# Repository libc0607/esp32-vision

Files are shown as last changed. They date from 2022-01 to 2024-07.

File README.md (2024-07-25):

本项目已停止更新，已停止任何形式的技术支持。但您仍然可以查看全部开源资料，并在遵守开源协议的情况下使用。  
如果您遇到任何问题，可以学习那位的美德后自行解决，也可以在教令院找阿帽。阿帽不好听吗？  

---

# ESP32 神之眼 Genshin Impact Vision

Inazuma_Electro_Demo (https://www.youtube.com/watch?v=uiCPUxYVVak "Inazuma_Electro_Demo")  

[Bilibili BV1Fr4y1z7yS: 下北泽元素力测试](https://www.bilibili.com/video/BV1Fr4y1z7yS)  
[Bilibili BV1ir4y1r7ZS: 给刻师傅做个神之眼](https://www.bilibili.com/video/BV1ir4y1r7ZS)  
[Bilibili BV1hS4y1D7fo：蒙德外壳+圆版 测试](https://www.bilibili.com/video/BV1hS4y1D7fo)  
[Bilibili BV1a34y1s7b5：稻妻外壳+圆版 测试](https://www.bilibili.com/video/BV1a34y1s7b5)  
[Bilibili BV13S4y1e7Yu：蓝牙切换视频测试](https://www.bilibili.com/video/BV13S4y1e7Yu)  
[Bilibili BV13S4y1e7Yu：须弥外壳](https://www.bilibili.com/video/BV1ma41197kk)  

**警告：如果你没有能够完全理解整个设计的能力，那就不推荐做。** 因为我也不知道又会遇到什么坑  

**这里不是 B 站 up [渣渣一块钱4个](https://space.bilibili.com/14958846) 的代码仓库**，别做错了。详情见下方 [消歧义补丁](https://github.com/libc0607/esp32-vision#%E6%B6%88%E6%AD%A7%E4%B9%89%E8%A1%A5%E4%B8%81) 一节  

如果你是第一次尝试电子制作，或是不确定能否在缺乏教程的情况下自行完成以 0402 元件为主的中高密度 PCB 焊接及调试，那么推荐你从 [渣渣一块钱4个：电子版璃月神之眼制作教程](https://www.bilibili.com/video/BV1HS4y1b7tQ) 做起，他的教程十分详细，难度和成本都比较低，可以快速做出一个能用的成品。  

另外我也有一个基于小渣渣的设计缩水的版本，使用他修改的外壳，基于 GPL 3.0 开源，对量产成本做了优化；  
见 [libc0607/vision-c3-youth](https://github.com/libc0607/vision-c3-youth)   
但我没有在量产，在卖的都不是我，所以我不是客服，遇到问题你自己看看源码（  

## 我想自己做一个，且不怕翻车，该从哪开始？ 
但是真的很容易翻车，如果你真的想好了……。  
你可以先看 [渣渣一块钱4个：电子版璃月神之眼制作教程](https://www.bilibili.com/video/BV1HS4y1b7tQ)，大体流程是相同的  

 - 参考 [PCB 设计](https://github.com/libc0607/esp32-vision#pcb-%E8%AE%BE%E8%AE%A1) 一节中的链接，在 LCEDA 中[导出 Gerber](https://docs.lceda.cn/cn/PCB/Gerber-Generate/index.html)，送到嘉立创下单（[PCB 下单指引](https://www.jlc.com/portal/server_guide_35092.html)）  
 - 如果你对自己的焊接水平没有自信，需要 SMT，还需要[导出 BOM](https://docs.lceda.cn/cn/Schematic/Export-BOM/index.html) 以及[贴片坐标](https://docs.lceda.cn/cn/PCB/Export-Coordinate/index.html)，参照[嘉立创的下单教程](https://www.jlc.com/portal/server_guide_35102.html)进行 SMT 下单
 - 拿到 PCB 后完成全部元件焊接，确保硬件没有问题 
 - 在 [Arduino IDE](https://www.arduino.cc/en/software) 中装好 [arduino-esp32](https://github.com/espressif/arduino-esp32) 环境，并按照代码前的注释信息安装好其他依赖  
 - 按照代码前的注释信息，编译并上传程序至板载的 ESP32 中，测试基本功能是否正常；你应该使用带有 EN 和 IO0 接口的 ESP32 下载器   
 - 下载[外壳的 STL 文件](https://github.com/libc0607/esp32-vision/tree/main/stl)，通过 3D 打印制作外壳；你也许会想要在 [三维猴](https://www.sanweihou.com/) 或 [未来工厂](https://www.wenext.cn/) 下单  
 - 将打印好的外壳进行打磨及喷漆，可以参考 [渣渣一块钱4个：外壳喷漆教程](https://www.bilibili.com/video/BV1cY4y1a7CQ) 
 - 按照对应[外壳文件夹](https://github.com/libc0607/esp32-vision/tree/main/stl)下的 README 进行外壳及整机的组装  
 - 按照 [代码 README](https://github.com/libc0607/esp32-vision/tree/main/src/vision_sdcard_mjpeg) 下的指引，上传文件至内部存储中，并进行参数配置
 - Enjoy!
 
如果你想在 渣渣一块钱四个 的设计中，移植使用蓝牙 iTag 进行遥控的代码，这里有一个我整理出来的最小示例大概能帮到你：[ble_itag_demo](https://github.com/libc0607/esp32-vision/blob/main/src/ble_itag_demo/ble_itag_demo.ino)  
 
## 硬件特性
以下描述的是 V3.3 版本的特性：  
 - 1.54 寸 LCD（方版）或 1.28 寸 LCD （圆版）
 - ESP32-PICO-D4 核心，可以 Wi-Fi 上传
 - 内部显示的内容作为图片或者视频存在，可以在 SPIFFS 或 SD Nand 中存放图片/视频，理论上可以 128M ~ 8G  
 - 内置 LIS2DW12 加速度传感器，支持敲击识别，重力感应功能觉得有点鸡肋就删了  
 - 外壳预留 TEMT6000 环境光强度传感器位置，12-bit（大约） PWM 调光
 - 锂电池充电管理使用 CN3165，带有 NTC 保护，通过电阻配置来支持 4.2V/4.35V/4.4V
 - 圆版电池 R40350 3.85V/435mAh，方版电池 403035 3.7V/450mAh
 - 低功耗 DC-DC 降压 ETA3425，低电量时 100% 导通，即断电电压由锂电池保护板决定  
 - 用了一个 SY6280AAC 让屏和 SD Nand 支持断电 
 - 支持且仅支持无线充电，需要外接无线充电模块并将线圈贴在外壳上；配套使用 华为 GT2 Pro 的无线充电座即可充电，淘宝大概卖 29  
 - 本体带有一个物理按键，暂时用于切换显示模式
 - 支持将 iTag 蓝牙防丢器作为按钮控制视频切换
 
本设计的整体思路是尽量省电，虽然 V3.3 增加了电池容量（…），但受体积限制和屏幕拖累，续航还是尿崩  
你可以通过修改配置文件，在显示效果和续航间选择合适的平衡；详见 [vision_sdcard_mjpeg](https://github.com/libc0607/esp32-vision/tree/main/src/vision_sdcard_mjpeg)  

由于 2022 年 6 月的某个时候嘉立创将 ESP32-PICO-D4 踢出了经济型 SMT，考虑到少量自制的可制造性，未来本设计很可能会因此做出一些调整；但 V3.3 已经是一个相对稳定的版本，如果你等不及了可以做或是自己修改。  
根据目前（2022.7）的[信息](https://t.me/avocado_leaks/4980)来看，须弥也是圆的，我猜电路大概是还能用的（吧…？），所以应该不用再大改了  

## PCB 设计  
PCB 圆版：   
V3.3: [OSHWHub: libc0607/esp32_vision_v3-3_gc9a01_rel](https://oshwhub.com/libc0607/esp32_vision_v3-3_gc9a01_rel)  

  

PCB 方版：  
V3.3: [OSHWHub: libc0607/esp32_vision_v3-3_st7789_rel](https://oshwhub.com/libc0607/esp32_vision_v3-3_st7789_rel)  
注：1.54 寸 ST7789 屏幕有很多厂家生产外形和引脚定义兼容的型号，但有一部分型号屏幕的侧面及背面漏光。  
由于把漆喷到一点都不漏光这件事不是很有操作性，所以推荐选择不漏光的版本；你可能需要问问卖家  
注2：屏幕可能存在色差，不同的屏色差不同，这个emmm就没什么低成本且可操作性强的解决方法，推荐把播放的视频用 AE 自己调个色  



关于本设计在 2022 年 6 月之前的物料成本，仅供参考：以每批次做 5 套为例，约为 120 ~ 140 元/套。  
该价格：不含消耗品及工具等；不考虑良率；不含邮费；PCB 白嫖嘉立创；SMT 贴基础库；  
其中由于屏幕价格，方版整体会比圆版便宜；整体数值可能随元器件价格波动（不过大概只会高吧x   
懒人包：648做5个，做不出来再补一单328（？）  

2022 年 7 月更新：由于 JLC 把 ESP32-PICO-D4 移出了经济版 SMT 可贴列表，单次贴片的工程费由原本的 50 元提高到了 150+50 元。（我这邮寄的还没用完呢你就涨价草（  
除非你自己搞得定 ESP32-PICO-D4 的手工焊接，否则这会带来很高的成本提升。  

## 软件
目前做了两版测试代码，可以实现基本功能，但都不算正式 Release。有待填坑；  

[vision_SPIFFS_GIF_video](https://github.com/libc0607/esp32-vision/tree/main/src/vision_SPIFFS_GIF_video)： 不贴 SD Nand，仅使用 ESP32 内部的 SPIFFS 作为存储的版本  
[vision_sdcard_mjpeg](https://github.com/libc0607/esp32-vision/tree/main/src/vision_sdcard_mjpeg)： 使用 SD Nand 作为存储，支持 Wi-Fi 上传，支持 OTA，支持蓝牙的版本  

vision_SPIFFS_GIF_video 为早期版本的产物，没有维护，不能保证运行在新版硬件上。  
后续主要更新会集中在 vision_sdcard_mjpeg 上  

## 外壳 
由于本人非专业，只在大二上过一晚上的 SolidWorks 课，原始工程的 SLDPRT 已经变成屎山，本着要脸的原则没有放出。  
但这里提供了 STL 格式的文件，可以直接拿去下单 3D 打印，想修改的话也可以逆向一下，或是使用如 C4D 等可以修改的软件自行修改。  

另，现版本由于个人不算满意，可能会继续改动，持续到我删掉这句话为止；请自行考虑风险。  

[蒙德版外壳在这](https://github.com/libc0607/esp32-vision/tree/main/stl/mondstadt)   

[璃月版外壳在这](https://github.com/libc0607/esp32-vision/tree/main/stl/liyue)    

[稻妻的](https://github.com/libc0607/esp32-vision/tree/main/stl/inazuma)  

   

   

  

## 参考 & 引用
两个软件例子都参考了 [moononournation/RGB565_video](https://github.com/moononournation/RGB565_video)   
以及 DFRobot_LIS 的 tapInterrupt 示例、ESP32 Arduino 中的 SDWebServer 和 OTAWebUpdater 示例  
蓝牙 iTag 部分参考自 [100-x-arduino.blogspot.com](http://100-x-arduino.blogspot.com/)  
元素图标来自 [Bilibili: 鱼翅翅Kira](https://space.bilibili.com/2292091)   
外壳的处理方法是从 @云梦泽创意空间 的群文件中学到的   
野兽先辈忘了从哪搞来的了。。  
如果还有遗漏请指出谢谢茄子  

## 消歧义补丁
**这里不是 B 站 up [渣渣一块钱4个](https://space.bilibili.com/14958846) 的代码仓库**，别做错了。  

我的设计和他的设计是**两套独立的设计，代码不通用，硬件不通用，外壳不通用**，开源协议也不同，只是碰巧外观都是神之眼。。  
如果你只是想要一颗挂件，被神明注视一下下，我推荐优先考虑他的设计，因为他的教程详细丰富，群里活人多，翻车严重的话还能买个他的核心板用；  
我的这边只有 Github 这点儿文档，还总是不更新，代码还有 bug，做了会被神明注释掉的（  

### A. [渣渣一块钱4个](https://space.bilibili.com/14958846) 的设计资料汇总
我这里仅作为参考，不对内容做保证，不保证完整性，以原作者为准，请自行检查是否有最新版。  
别做错了，别做混了，别问我哪里和哪里能不能通用。。。  
圆版 PCB：[OSHWHub: 神之眼挂件V1.1](https://oshwhub.com/Myzhazha/esp32_pico-d4-video)  
方版 PCB：[OSHWHub: 璃月神之眼挂件](https://oshwhub.com/Myzhazha/li-yue-shen-zhi-yan-gua-jian)  
方版教程：[渣渣一块钱4个：电子版璃月神之眼制作教程](https://www.bilibili.com/video/BV1HS4y1b7tQ)  
方版效果：[渣渣一块钱4个：璃月电子版神之眼](https://www.bilibili.com/video/BV1DY4y1b7GN)  
圆版教程：[渣渣一块钱4个：电子版神之眼（蒙德）开源说明](https://www.bilibili.com/read/cv15460352)  
圆版安装：[渣渣一块钱4个：神之眼圆形核心板安装教程](https://www.bilibili.com/video/BV1KB4y1m7H2)   
圆版效果：[渣渣一块钱4个：稻妻和蒙德电子版神之眼](https://www.bilibili.com/video/BV1sF411g7tc)    
外壳下单：[渣渣一块钱4个：神之眼外壳3D打印平台打印教程](https://www.bilibili.com/read/cv16117622)  
外壳喷漆：[渣渣一块钱4个：外壳喷漆教程](https://www.bilibili.com/video/BV1cY4y1a7CQ)   
视频格式转换：[渣渣一块钱4个：使用FFmpeg转换mjpeg格式](https://www.bilibili.com/read/cv15713513)  

他的 QQ 群：636426429  
他后续会制作大尺寸（大约你家墙上86盒那么大）的神之眼，而我暂时没有计划，如果需要可以关注他。  

### B. [我](https://space.bilibili.com/6509521) 的设计资料汇总
……就 全都在这 没别的了（   

### 我的设计和他的设计的关系

 - 电路部分各做各的，不通用，不过也有相互参考   
 - 程序部分各做各的，不通用  
 - 他的蒙德外壳和璃月外壳基于我的修改，但不通用
 - 他卖核心板（不含外壳），我不对外卖，所以想买的去找他
 - 他的外壳为 CC BY-NC-SA 协议，其余部分为 GPL 协议；我的全部设计为 CC BY-NC-SA 协议  

## 许可
本设计采用 [CC BY-NC-SA 4.0](http://creativecommons.org/licenses/by-nc-sa/4.0) 许可。（OSHWHub 上只能选 3.0 ..）  
我不卖成品，也不以任何形式卖套件，没精力搞。。  
但作为开源项目，你当然可以在遵守开源协议的情况下自己做一个玩；NC 是为了防止潜在的mhy法务部警告（？）。  
如果你还是充满好奇，可以看看 [《原神同人周边大陆地区正式运行指引V1.2》](https://weibo.com/ttarticle/p/show?id=2309404707028085113324)（不保证这里链接是最新版，请自己确认）  

## 免责声明  
这东西仅为个人 DIY 项目，作者不保证所公开的内容绝对可用，也不可能解决所有出现的问题。  
本设计的全部设计资料都已开源，这里的内容足够从零开始制作一个完全可用的成品，没有那种祖传的隐藏细节。  
如果你对组装细节有不清楚的地方，可以联系我补全，但我只会直接补全到 Github 上，以便他人参考。  
你应该考虑到所有可能存在的风险，包括但不限于各种可能的人身伤害、金钱损失和 Emotional Damage。  
滥用本项目造成的一切负面效果与作者无关，最终解释权归作者所有。

说真的，不推荐做，又费钱又费时间又容易翻车，还容易因为自己太菜而受到精神打击（

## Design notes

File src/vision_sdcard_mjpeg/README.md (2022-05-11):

# vision_sdcard_mjpeg
这里是 ESP32 Vision 的测试代码之一。  
由于 SPIFFS 的容量只能够存十秒上下的 GIF，很多花活可能整不出来；这个 Demo 使用了板上容量可高达 8GB 的 SD Nand 来支持整活。   
注：由于加入蓝牙时这堆代码已经变成屎山了，目前的蓝牙部分还有各种各样的 Bug，emmmm……  

## 测试效果 
[Bilibili BV13S4y1e7Yu](https://www.bilibili.com/video/BV13S4y1e7Yu)  
这里用于演示的视频片段见 [hydro_unaligned](https://github.com/libc0607/esp32-vision/tree/main/src/vision_sdcard_mjpeg/hydro_unaligned) 目录下  

## 硬件
目前版本的代码可配合 硬件版本 V3.3 使用。  
蓝牙按钮使用一种叫做 iTag 的防丢器，它的协议相比模拟 HID 键盘的蓝牙按钮要简单很多，比如淘宝上的 [这个](https://item.taobao.com/item.htm?id=556798481873)  
关于如何将 iTag 作为 ESP32 的输入按钮使用，这里有一个最小化的例程： [ble_itag_demo](https://github.com/libc0607/esp32-vision/tree/main/src/ble_itag_demo)  

这个例子没有使用到板上那个 0402 封装的 NTC；其他的电路，包括外接的环境光传感器以及 NTC 电阻都需要焊接才能正常工作。  
这个例子通过修改代码的方式同时支持 方版（ST7789）和 圆版（GC9A01），修改方式见下文。  

## 功能
 - 冷启动后，屏幕变灰，尝试连接名为 Celestia，密码为 mimitomo （默认，可在源码中更改）的 Wi-Fi  
 - 如果超时未连接成功则进入正常工作周期；短按按键超过 250ms 可以跳过这个超时过程  
 - 如果连接成功，屏幕变蓝，同时开启一个 WebServer，通过浏览器 http 访问该设备，可以上传 mjpeg 视频到 SD 卡中，可以修改配置文件
 - 上传过程中屏幕会变成橘色，LED 闪烁，上传结束后变回蓝色
 - 短按按键退出上传模式
 - 播放视频时可以按下按键暂停，短按暂停则进入浅度睡眠并关闭屏幕和背光；按下超过一秒（默认）则保持当前帧，开最大背光，进入浅度睡眠；再次按下会恢复播放
 - 循环模式：可以选择循环播放（常亮），或是播放视频一次后进入深度睡眠
 - 深度睡眠时，通过双击唤醒或者定时器唤醒（按键由于不是 RTC IO，无法用于深睡唤醒）
 - 如果近期使用过双击唤醒或是按下过按键，则接下来的几次定时器唤醒会较快，反之亦然
 - 如果电量低，它就也不亮了 （？又废话）
 - 支持动态亮度调节
 - 支持通过配置文件选择播放的 mjpeg，支持在网页中预览 mjpeg 文件（…的第一帧）
 - 支持通过配置文件设置屏幕方向
 - 支持在网页中 OTA 升级固件
 - 播放掉帧，性能堪忧（
 - 任何时候长按超过三秒都会被断电或是上电
 - 蓝牙启用后，可以使用蓝牙连接 iTag 来控制在两段视频间平滑切换（可能仍存在 bug（

## 编译 & 上传 & 初始化设置 

1. 安装 Arduino  
2. 安装 [espressif/arduino-esp32](https://github.com/espressif/arduino-esp32)  （仅在 V1.0.6 下测试过；高版本和下面某个库的兼容不好）
3. 安装 [moononournation/Arduino_GFX](https://github.com/moononournation/Arduino_GFX)  
4. 安装 [bitbank2/JPEGDEC](https://github.com/bitbank2/JPEGDEC)  
5. 安装 [DFRobot/DFRobot_LIS](https://github.com/DFRobot/DFRobot_LIS)  
6. 安装 [stevemarple/IniFile](https://github.com/stevemarple/IniFile)  
7. 下载这坨源码，打开
8. 选择：ESP32 Dev Module, 240MHz CPU, 80MHz Flash, DIO, 4MB(32Mb), (1.9M/190k), PSRAM Disable  
9. 上传
10. 建立名为 Celestia， 密码为 mimitomo 的 2.4GHz Wi-Fi，该网络中需要提供 DHCP 服务；（就是用电脑或者手机开热点的意思；并且由于需要加载 js，这个热点需要能访问互联网）  
11. 给板子上电  
12. 当看到板子连入该 Wi-Fi 后，在 DHCP 地址池中找到该设备，记录下其 IP 地址
13. 使用浏览器 http 打开其 IP 地址，下文以 192.168.1.200 为例；如果你的网络中支持 MDNS 服务也可以打开 http://vision.local    
14. 使用 curl 或是其他什么你熟悉的东西上传 index.htm, edit.htm, ota.htm 三个网页文件：curl -X POST -F "file=@index.htm" http://192.168.1.200/edit
15. 将你需要播放的东西通过 ffmpeg 或是其他的什么方式转为 240x240，大约 24fps 的 mjpeg 格式文件 （参考 [RGB565_video](https://github.com/moononournation/RGB565_video) 中的示例）
16. 使用浏览器打开 http://192.168.1.200 或 http://vision.local ，选择 “文件”，并使用上方的按钮上传 mjpeg 文件到 SD Nand 根目录
17. 在左侧列表中找到 config.txt 并编辑，设置 video 为需要播放的文件名，以 / 开头，例如 video=/loop.mjpeg， Ctrl+S 保存；该文件的语法参考 [stevemarple/IniFile](https://github.com/stevemarple/IniFile)   
18. 短按按键，看到屏幕一绿即为配置完成
19. 你就又获得了一颗下北泽神之眼 
20. 如果想要再次更改其中内容，只需要将其断电（板上开关）等个十几秒后再接通让它冷启动，即可重复上述相关步骤。

## 自定义配置 

配置文件 /config.txt 中的可自定义内容：   

```
 [vision]
 video=/loop.mjpeg           # 要播放的文件名。需要以 / 开头，并且文件名不要超过 8 个字符（短文件名），不然会出bug
 lcd_rotation=0              # LCD 的方向。取值范围 0~3，对应 0°, 90°, 180°, 270°，根据实际情况修改
 loop_mode=false             # 循环开关
 abloop_en=false             # 使能两段视频切换
 ble_mac=00:12:34:56:78:9a   # 你的 iTag 的 MAC 地址。可以通过例如 nRF Connect 这样的应用查看
```
目前的设定中，有 3 种工作模式：  
(a). 循环播放两段视频，通过 iTag 或双击来控制两段视频的切换  
 该模式下需要剪出 4 段视频，两个循环片段 a_loop 及 b_loop，以及两个过渡片段 a_setup 和 b_setup；   
 - loop_mode = true
 - abloop_en = true
 - ble_mac = \<iTag MAC address\>
 - 上传 /a_setup.mjpeg, /a_loop.mjpeg, /b_setup.mjpeg, /b_loop.mjpeg  
  
 Light Sleep后蓝牙连接会断开，需要等几秒才会重新连接  
 LED 会指示当前正在播放的是 A 视频还是 B 视频；  
 
(b). 循环单个视频
  该模式需要一段视频
 - 上传视频 (例如 hydro.mjpeg)
 - loop_mode = true
 - abloop_en = false
 - video = hydro.mjpeg
 
 (c). 单次播放后进入睡眠，通过双击唤醒
  该模式需要一段视频
 - 上传视频 (例如 hydro.mjpeg)
 - loop_mode = false
 - video = hydro.mjpeg

如果你想恢复默认值，只需要删除 /config.txt 并重启即可，会生成一个新的默认配置的文件。  
按键功能仅在 (a) (b) 下生效   

代码中有几个可以配置的地方（其中一部分可能在日后（如果有，咕）的版本中移入配置文件）：  
```

// 系统配置
#define CONFIG_FILENAME "/config.txt"       // SD Nand 根目录中的配置文件的名称。该文件如果不存在会自动生成。 
#define DEEP_SLEEP_SHORT_S  6               // 在最近一次敲击唤醒之后的 DEEP_SLEEP_SHORT_CNT 次睡眠前，会设置定时器使用 DEEP_SLEEP_SHORT_S 作为唤醒延时；否则使用 DEEP_SLEEP_LONG_S
#define DEEP_SLEEP_SHORT_CNT  6             // 每次检测到敲击唤醒后重置计数器
#define DEEP_SLEEP_LONG_S   30              // DEEP_SLEEP_LONG_S 和 DEEP_SLEEP_SHORT_S 是定时器唤醒的时间，单位是秒
#define BAT_ADC_THRESH_LOW  1700            // 低电压保护。当每一轮工作开始时，如果 ADC 读取到的电压读数低于这个值，就不会播放 GIF，直接进入下一轮睡眠
                                            // 由于 ESP32 的 ADC 质量不咋样，并且电池的截止电压也各自不同，所以没有换算成电压。
                                            // 你可以根据自己板子的情况尝试调节这个值。  

// 屏幕配置
//Arduino_GC9A01  *gfx = new Arduino_GC9A01(bus, PIN_TFT_RST, 2, true);
Arduino_ST7789  *gfx = new Arduino_ST7789(bus, PIN_TFT_RST, 0, true, 240, 240, 0, 0, 0, 80);
                                            // 在这里选择你的屏幕种类
#define LCD_BACKLIGHT_MIN_8B  16            // 屏幕背光的最低亮度，范围为 8bit（即最大值为 255）。
                                            // 每次运行时，程序将从环境光传感器那里得到的光强度 Map 到 LCD_BACKLIGHT_MIN_8B ~ 255 区间内，作为背光 PWM 的占空比。
#define LCD_PWM_FIR_LEN 32                  // 让背光的动态调节不要那么突然

// 网络设置
const char* wifi_ssid = "Celestia";         // 冷启动时尝试连接的 Wi-Fi 名称和密码
const char* wifi_pwd = "mimitomo";
#define WIFI_CONNECT_TIMEOUT_S 20           // 冷启动时尝试连接 Wi-Fi 的时间上限，单位为秒。
                                            // 超过这个时间还没有连接成功则直接进入正常工作，也可以用按键跳过
const char* wifi_host = "vision";           // MDNS 主机名。这样设置得到的结果形如 vision.local                             

```
## 早期版本
由于早期使用的分区是默认的 1.2M/1.2M/1.5M，加入 BLE 后空间不够了。。所以 BLE 版本改了分区  
加入 BLE 前的最后一个版本为 [78b3749](https://github.com/libc0607/esp32-vision/commit/78b3749)  

## TO-DOs
本来想用 ESP-NOW（例如 [Picoclick](https://github.com/makermoekoe/Picoclick-C3)），但国内好像没有那种买来就能用的  
iTag 虽然使人逻辑混乱，但有商品卖，且足够便宜，先凑合用着  

## 参考 
[moononournation/RGB565_video](https://github.com/moononournation/RGB565_video)   
ESP32 Arduino 中的 SDWebServer 和 OTAWebUpdater 示例  
雷元素图标来自 [Bilibili: 鱼翅翅Kira](https://space.bilibili.com/2292091)  
BLE iTag 相关代码抄自 [100-x-arduino.blogspot.com](http://100-x-arduino.blogspot.com/2018/05/itag-i-arduino-ide-czy-esp32-otworzy.html)  

## 免责声明  
这段代码仅用作测试，由于滥用造成的一切不好的后果和作者无关。  
如果其中的图片素材涉及侵权，请联系我删除。  
这段代码仅调通了功能，结构十分混乱，如有引发不适与我无关。

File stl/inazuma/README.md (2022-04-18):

# ESP32 Vision 稻妻版外壳组装指引  
 当前外壳版本 V1.1，适配圆版 PCB V3.3  

由于都是圆的和蒙德版基本一致，这里就只写不同的部分  

## 材料清单
这里仅列出与蒙德版的不同  
| 名称 							| 数量	| 备注					|
| :---							| :---		| :---					|
| M1.2\*4 螺丝 | 4  | |
| R40350 锂电池  | 1 |  |

## 安装  
过程基本与蒙德版一致，这里就随便放几个图  

  

  

  



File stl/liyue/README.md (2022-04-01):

# ESP32 Vision 璃月版外壳组装指引

当前外壳版本 V2.2，适配 PCB 版本 V3.3 ST7789  
由于外壳更新可能会出现教程图片前后不兼容的情况，这里保留了最初版的教程没有改动，版本更新带来的变动会单独列在下面；但具体可能还是要自己发挥一下  

本安装指引的内容仅作为参考，不作为标准流程，可能会随时间推移而失效。请一定清醒一点带着脑子，搞明白自己做的是什么该怎么做，造成损失自负。  
作为一个 DIY 项目，它当然充满瑕疵，过程中还可能会出现各种问题，还请自行发挥。  
作者保留最终解释权。  

## 材料清单
注：这里的淘宝链接没有任何利益关系，只是为了方便说明。你可以随便买。
| 名称 							| 数量	| 备注					|
| :---							| :---		| :---					|
| liyue-main*.STL				| 1			| 本体 	|
| liyue-cap*.STL					| 1			| 盖子					|
| 焊接调试好的电路板及屏幕		| 1			|						|
| 403035(~450mAh) 或稍小尺寸的锂电池		| 1			| 403035是最大的，其余能不能塞得进去自己判断 |
| NTC 热敏电阻 10k B3380 		| 1			| 焊线的那种，粘在电池旁边测温度的 |
| M1.2\*3 圆头螺丝 国标 					| 6		| 可以多买一点备用，头部什么形状其实……没所谓？						|
| M1.2  螺母 					| 6		| 可以多买一点备用，要确定它和上面的能拧到一起就行						|
| M1.5\*4 平头铜铆钉 | 1 | 	用作按键。例如 [这个](https://detail.tmall.com/item.htm?id=15757285605) |
| O型密封圈，外径3mm内径1.4mm线径0.8mm	| 可选 |	例如 [这个](https://item.taobao.com/item.htm?id=614352089868)。套在上面的铆钉上。它仅起到改善手感的功能，可以不用，反正也不可能防水的，我写是因为买都买了。。|
| FPC 排线 4P 1.5mm间距 3cm长 	| 1 		| 不是那种常见白色的，一定要耐高温（茶色），比如 [这个](https://item.taobao.com/item.htm?id=639292801110)	|
| TEMT6000X01 环境光传感器		| 1			| 焊到上面的排线上					|
| 无线充电用的隔磁片			| 若干		| 虽然下面模块会送，但需要两层|
| Qi 协议的无线充电接收模块 	| 1			| 比如 [这个](https://item.taobao.com/item.htm?id=626465407103) ；买线圈大一点的版本 |
| 线圈							| 可选		| 接收模块送的线圈比较小，如果你使用下面提到的充电座则可以换一个稍大的线圈来提高效率；对于这些常见接收模块，选择电感量 10uH ~ 12uH，直径不超过 34mm 即可，比如芯科泰的 L93 和 L104 都实测可用 |
| Qi 协议的无线充电发射模块		| 可选		| 外壳是按照 华为 GT2 Pro 的充电座的外形画的，那个充电器淘宝大概不到30，买来直接吸上就能用；也可以在接收模块同一家买|
| 30mm 边长正方形的低弧的玻璃  	| 1			| 比如 [这个](https://item.taobao.com/item.htm?id=591580399917) ；建议多买一点，运输过程中可能撞出裂痕，需要挑选|
| 透明的胶水 					| 若干		| 需要能仅依靠外壳那一圈的面积粘得住那一大块玻璃，我用的是 维修佬 E8000 | 
| 8mm 直径， 1mm 厚的强磁铁		| 1			| 和 华为 GT2 Pro 充电器 一起使用时，用来吸附定位 |
| 自喷漆，金色（香槟金）		| 若干		| 外壳上色	|
| 自喷漆，光油					| 可选 		| 喷了有点脏，不喷金色容易掉，自己选		|
| 马克笔，金色					| 可选		| 用于补瑕疵；手残建议买，颜色需要和上面自喷漆一致	|
| 美纹纸胶带					| 若干		| 喷漆时用	|
| 砂纸 | 可选 | 用来打磨 3D 打印件上由于支撑带来的瑕疵，需要细一点的，我用的 2000 感觉粗了，建议 2000 5000 10000 各买一点 |
| 补土 | 可选 | 如果 3D 打印件上有坑就自己补一下，我买的田宫那个感觉还行 |
| 漆包线| 可选 | 那种耳机线材。比如我买的 [这个](https://item.taobao.com/item.htm?id=650753503748) |  
| 青稞纸 | 可选 | 如果是大电池，贴在电池上防止被电路板上的元件划伤|

### 外壳喷漆  
拿出 3D 打印的外壳。检查外观，如果有坑就用补土填一下（下面的图都没有使用，按实际情况来）；    
使用粗砂纸和细砂纸打磨表面至没有明显的支撑凸起；     
使用美纹纸胶带将不想被喷漆的位置覆盖好，然后使用自喷漆在表面薄薄地均匀地喷涂数次。    

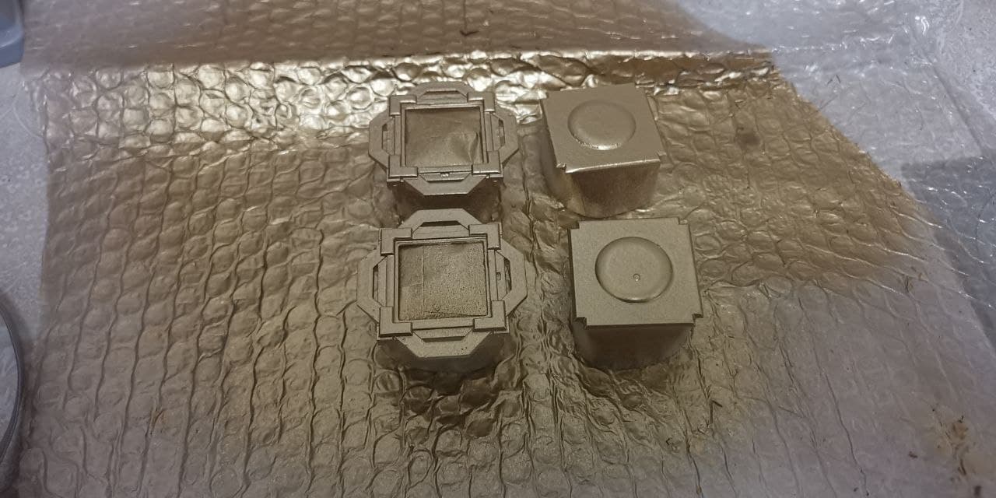
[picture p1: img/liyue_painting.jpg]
  

### 粘贴玻璃 
挑选一块没有裂痕没有瑕疵的 30 mm 边长低弧方形形玻璃。  
由于成本原因，它在运输过程中很容易出现刮花或者裂痕，所以建议多买一些到手后再挑；并且方的还有个更坑的问题，它四个角的圆角半径经常就tm不一样。。。还得挑   
同样地，装配过程中也要小心碰撞。方形玻璃建议按照实际用量的 4~5 倍购买，不然可能不太好挑。    

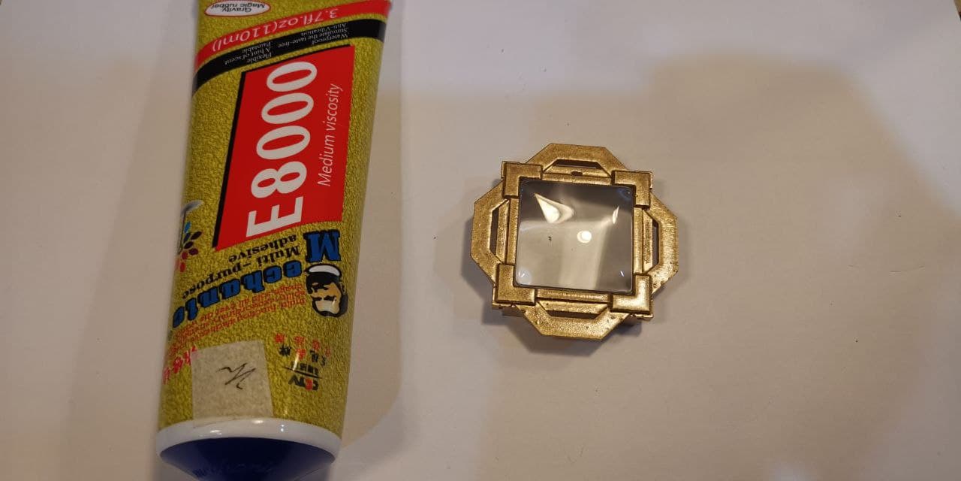
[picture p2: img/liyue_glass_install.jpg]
   

在外壳上均匀地挤一圈胶水，不要太多但是要能填满空隙，然后将玻璃放上去。注意要从多个侧面角度确认玻璃是否水平。  
由于 3D 打印精度和各地气温不同等原因，你可能需要在涂胶水前试一下玻璃能不能塞得进去。  
放上玻璃后胶水会溢出一些，我是将浸湿酒精的无尘布裹在镊子头部擦掉它们的，你也可以自由发挥。  
清理好溢出的胶水后，再次确认玻璃水平，使用美纹纸胶带将玻璃与外壳固定。我选择的这个胶水的固化大概需要一至两天，固化后暂时还没遇到过强度问题。  

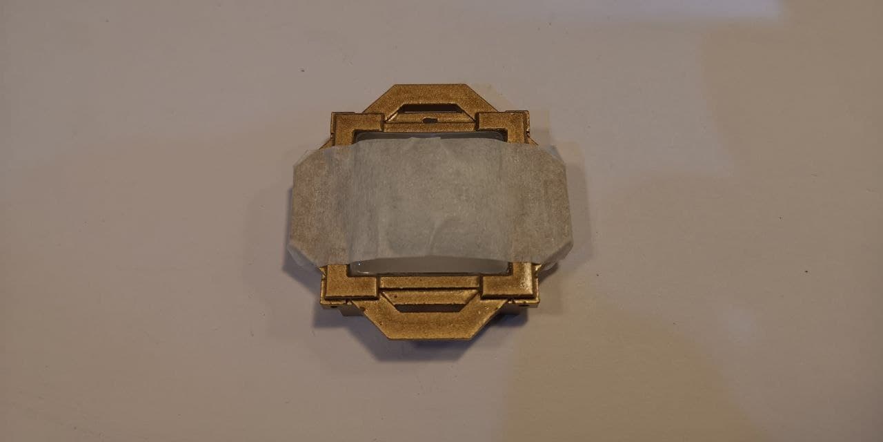
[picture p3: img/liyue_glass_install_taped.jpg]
  

### 安装环境光传感器  
准备一个 TEMT6000X01 环境光传感器，一条上表中提到的排线和胶水。  
将传感器如下图所示焊接在排线的引脚上。你可能需要像图上那样记录下引脚关系。  

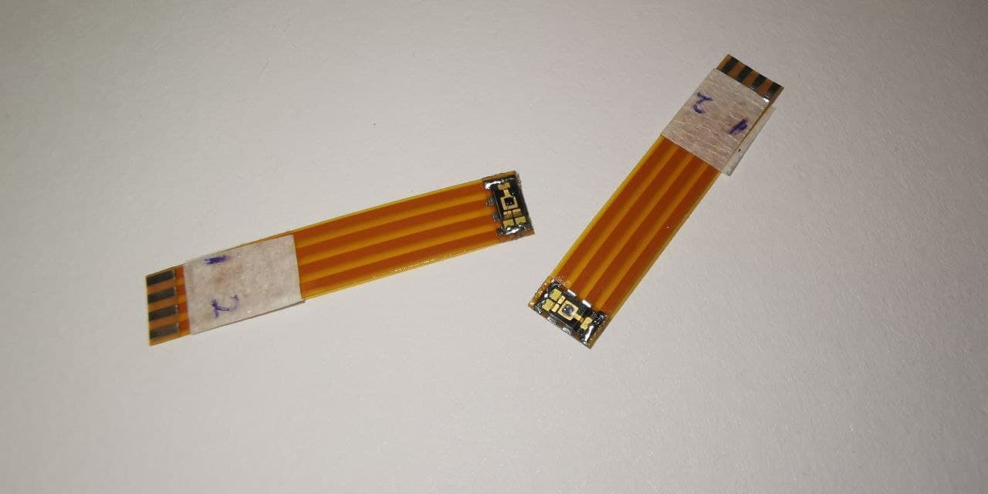
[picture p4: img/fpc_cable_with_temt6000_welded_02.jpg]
  

然后小心地将传感器所在位置折弯 90° 如下：  

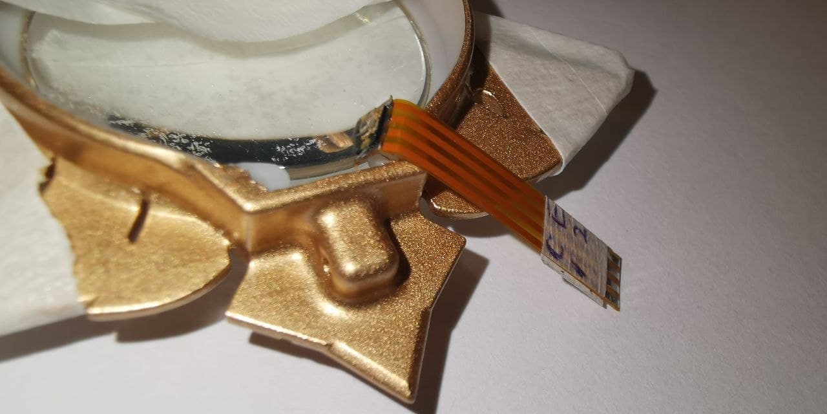
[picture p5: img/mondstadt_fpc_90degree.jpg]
  

在外壳的对应孔位挤一点胶水，并将传感器粘到孔中。  
使用美纹胶固定好玻璃和传感器，等待胶水固化，大约需要两天。  

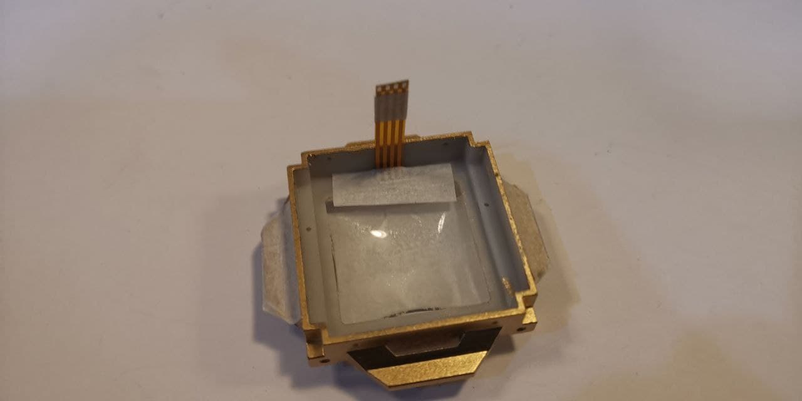
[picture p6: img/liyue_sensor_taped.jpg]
  

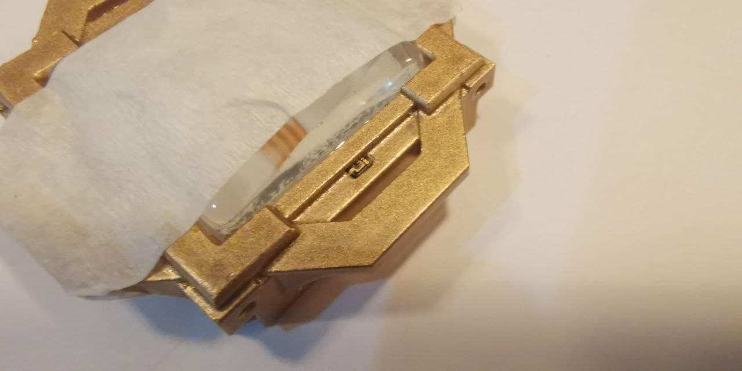
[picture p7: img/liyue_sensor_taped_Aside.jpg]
  

### 安装固定电路板用的螺母
在屏幕内侧有两个螺母位置，用来固定电路板。你需要把 2 颗 M1.2 螺母塞进去。内部情况如下图，平边与屏幕边缘平行。  

  

  

这里没有实物图，又是忘了拍了  

### 组装后壳 

后壳上需要嵌入剩下的 8 颗 M1.2 螺母。见下图，一共就八个坑  
将无线充电用的定位磁铁通过胶水粘贴在最大的坑里，注意和充电座放在一起试一下，别贴反了。。。  
确定极性后，用美纹胶带辅助定位，需要两天固化。

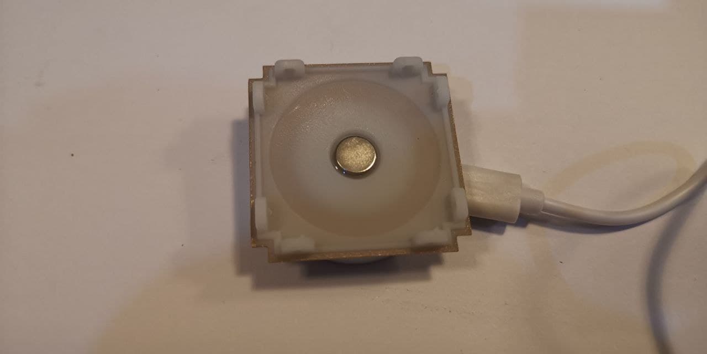
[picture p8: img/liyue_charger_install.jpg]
  

将无线充电的线圈粘贴上。  

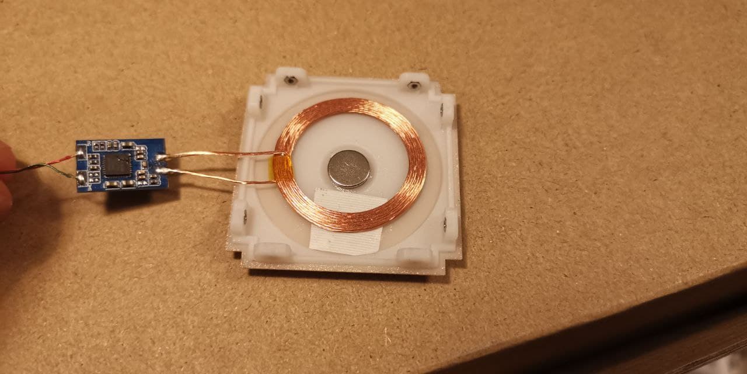
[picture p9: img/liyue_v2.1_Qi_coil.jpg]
    

按照后盖尺寸裁剪两片铁氧体隔磁片：  

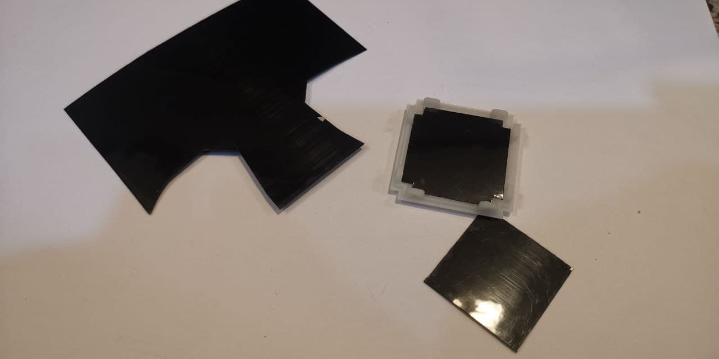
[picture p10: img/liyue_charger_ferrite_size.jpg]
  

将第一层隔磁片粘贴在线圈上，将无线充电模块粘贴在第一层隔磁片上；  

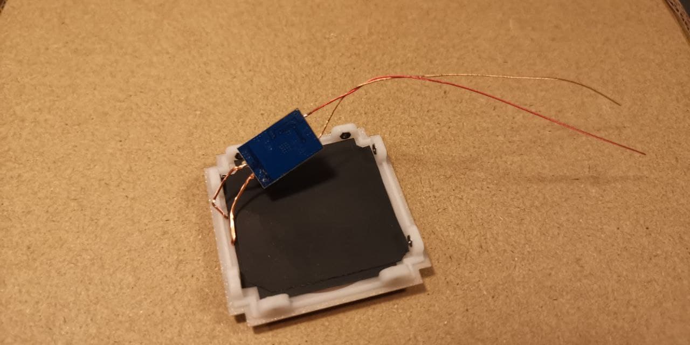
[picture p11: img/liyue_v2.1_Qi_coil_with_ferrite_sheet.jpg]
   

最后将第二层隔磁片粘贴在无线充电模块上，确保 PCB 上空有一层完整的隔磁片（下面几张图中并未安装，但实际需要）。  

### 安装电路  

你可以选择在安装电路板前先刷写固件。刷固件指引见 [/src](https://github.com/libc0607/esp32-vision/tree/main/src) 目录下，根据你的需要选择固件。  
由于这个 1.54 寸液晶屏背面不是金属，所以背面可以不贴绝缘胶带。  

按照引脚定义焊接好：环境光传感器的 2 条线；无线充电模块 2 条线；电池和 NTC 电阻共 3 条线（共用 GND）。    
如果发现原配的导线较硬，导致难以装配，可以将你不喜欢的线换成材料清单中提到的耳机线，将外皮剥掉使用线芯。  
完整的电路连接如下图。

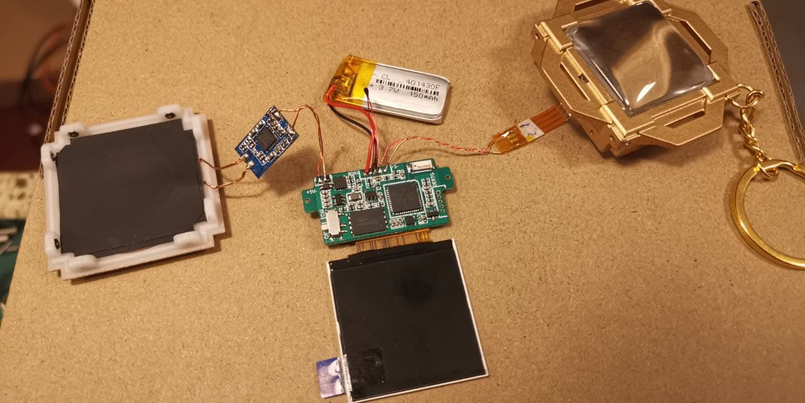
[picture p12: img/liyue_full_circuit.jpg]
   

将这些电路塞进去： 

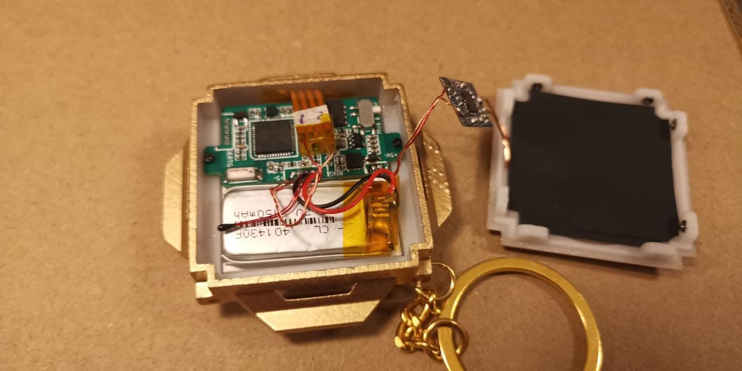
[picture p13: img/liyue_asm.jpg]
  

使用 2 颗 M1.2 螺丝将 PCB 固定在外壳上。盖上盖子，拧好周围的 8 颗螺丝，装配完成。 

--- 

### PCB V3.3 (STL V2.2) 改动  

#### 按键
PCB V3.3 (STL V2.2) 版本在侧面增加了一个按键，需要将按键塞进按键孔后再放入屏幕和电路板，像这样：  

  

  

尝试按动，能够按下能够回弹即可。在铆钉上套一个 O 型圈可以让它的手感更好一点，不过没有的话影响也不大。  

#### 电池安装
由于换用了403035 电池，安装结构需要做出调整：将无线充电模块贴在屏幕背面，然后将电池整个盖上去。  
你可能需要在电池上贴一层青稞纸来保护电池。  

#### 光传感器 
PCB V3.3 (STL V2.2) 版本为了正面美观，将光传感器移动到了侧面。  
按照同样的方式粘贴即可。

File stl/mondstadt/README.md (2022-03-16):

# ESP32 Vision 蒙德版外壳组装指引  
 
当前外壳版本 V2.3，适配圆版 PCB V3.3  
由于外壳更新可能会出现前后不兼容的情况，还是自己发挥一下  

本安装指引的内容仅作为参考，不作为标准流程，可能会随时间推移而失效。请一定清醒一点带着脑子，搞明白自己做的是什么该怎么做，造成损失自负。   
作为一个 DIY 项目，它当然充满瑕疵，过程中还可能会出现各种问题，还请自行发挥。  
作者保留最终解释权。  
（其实很多细节都和游戏中的模型有出入，暂时还没改的原因是因为 SolidWorks 水平太烂，SLDPRT 里变成屎山了，想改都没法改（（）  

## 材料清单
注：这里的淘宝链接没有任何利益关系，只是为了方便说明。你可以随便买。
| 名称 							| 数量	| 备注					|
| :---							| :---		| :---					|
| mondstadt-main*.STL			| 1			| 本体 	|
| mondstadt-cap*.STL				| 1			| 盖子					|
| 焊接调试好的电路板及屏幕		| 1			|						|
| 401120 或相近尺寸的锂电池		| 1			| 能不能塞得进去自己判断 |
| NTC 热敏电阻 10k B3380 		| 1			| 焊线的那种，粘在电池旁边测温度的 |
| M1.2\*4 圆头螺丝 					| 2/4			| 可以多买一点备用；大电池版仅用到 2 个						|
| M1.2\*6 圆头螺丝 					| 2			| 仅大电池版用到，可以多买一点备用						|
| M1.2 螺母 | 4 | 能和上面的螺丝拧到一起就行 |
| M1.5\*3 平头铜铆钉 | 1 | 用作按键。例如 [这个](https://detail.tmall.com/item.htm?id=15757285605) |
| O型密封圈，外径3mm内径1.4mm线径0.8mm| 可选 | 例如 [这个](https://item.taobao.com/item.htm?id=614352089868)。套在上面的铆钉上。它仅起到改善手感的功能，可以不用，反正也不可能防水的，我写是因为买都买了。。 |
| FPC 排线 4P 1.5mm间距 3cm长 	| 1 		| 不是那种常见白色的，一定要耐高温（茶色），比如 [这个](https://item.taobao.com/item.htm?id=639292801110)	|
| TEMT6000X01 环境光传感器		| 1			| 焊到上面的排线上					|
| 无线充电用的隔磁片			| 若干		| 虽然下面模块会送，但看情况可能需要两层|
| Qi 协议的无线充电接收模块 	| 1			| 比如 [这个](https://item.taobao.com/item.htm?id=626465407103) ；买线圈大一点的版本 |
| 线圈							| 可选		| 接收模块送的线圈比较小，如果你使用下面提到的充电座则可以换一个稍大的线圈来提高效率；对于这些常见接收模块，选择电感量 10uH ~ 12uH，直径不超过 34mm 即可，比如芯科泰的 L93 和 L104 都实测可用 |
| Qi 协议的无线充电发射模块		| 可选		| 外壳是按照 华为 GT2 Pro 的充电座的外形画的，那个充电器淘宝大概不到30，买来直接吸上就能用；也可以在接收模块同一家买|
| 35mm直径圆形的低弧的玻璃  	| 1			| 比如 [这个](https://item.taobao.com/item.htm?id=591580399917) ；建议多买一点，运输过程中可能撞出裂痕，需要挑选|
| 透明的胶水 					| 若干		| 需要能仅依靠外壳那一圈的面积粘得住那一大块玻璃，我用的是 维修佬 E8000 | 
| 8mm 直径， 1mm 厚的强磁铁		| 1			| 和 华为 GT2 Pro 充电器 一起使用时，用来吸附定位 |
| 自喷漆，金色（香槟金）		| 若干		| 外壳上色	|
| 自喷漆，光油					| 可选 		| 喷了有点脏，不喷金色容易掉，自己选		|
| 马克笔，金色					| 可选		| 用于补瑕疵；手残建议买，颜色需要和上面自喷漆一致	|
| 马克笔，黑色					| 1			| 用于给外壳上黑色的那几个位置涂色	| 
| 美纹纸胶带					| 若干		| 喷漆时用	|
| 砂纸 | 可选 | 用来打磨 3D 打印件上由于支撑带来的瑕疵，需要细一点的，我用的 2000 感觉粗了，建议 2000 5000 10000 各买一点 |
| 补土 | 可选 | 如果 3D 打印件上有坑就自己补一下，我买的田宫那个感觉还行 |
| 漆包线| 可选 | 那种耳机线材。比如我买的 [这个](https://item.taobao.com/item.htm?id=650753503748) |

### 外壳喷漆  
拿出 3D 打印的外壳。检查外观，如果有坑就用补土填一下（下面的图都没有使用，按实际情况来）；  
使用粗砂纸和细砂纸打磨表面至没有明显的支撑凸起；   
然后使用美纹纸胶带将不想被喷漆的位置覆盖好，然后使用自喷漆在表面薄薄地均匀地喷涂数次。  

如果上一步打磨过程中出现了奇怪的坑或者划痕，可以适当多喷一点点，但最忌心急喷一大堆。   

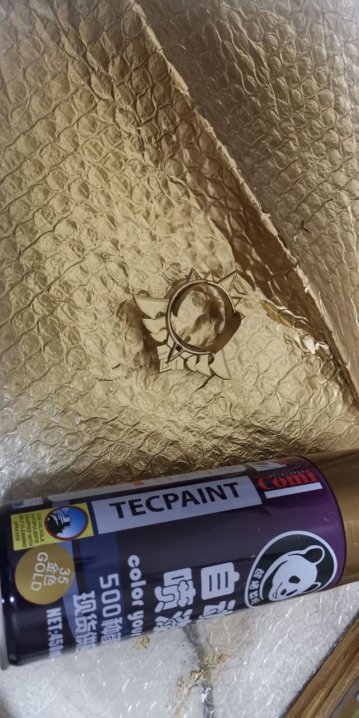
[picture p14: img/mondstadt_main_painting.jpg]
  
  

喷漆过程中请注意防护。等干透了再摸它。。  

喷光油的步骤可选，喷了的话外表显得有些脏，可能是我水平太烂（？）；不喷的话金色漆面可能容易掉。 

完成喷漆后，使用黑色马克笔把该涂成黑色的位置涂黑：  
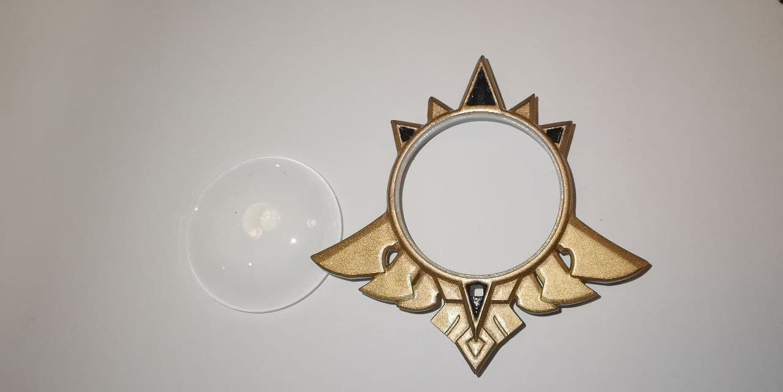
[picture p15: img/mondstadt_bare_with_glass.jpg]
  

### 粘贴玻璃 
挑选一块没有裂痕没有瑕疵的 35 mm 直径低弧圆形玻璃。  
由于成本原因，它在运输过程中很容易出现刮花或者裂痕，所以建议多买一些到手后再挑；同样地，装配过程中也要小心碰撞。我买过两批，总体良率大概在一半左右。    

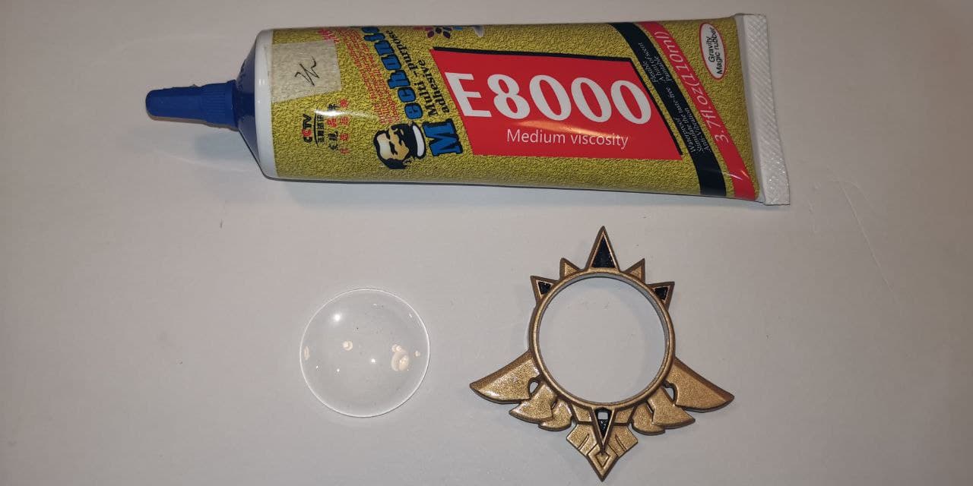
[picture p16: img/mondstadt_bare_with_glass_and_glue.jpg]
   

在外壳上均匀地挤一圈胶水，不要太多但是要能填满空隙，然后将玻璃放上去。注意要从多个侧面角度确认玻璃是否水平。  
由于 3D 打印精度和各地气温不同等原因，你可能需要在涂胶水前试一下玻璃能不能塞得进去。  
放上玻璃后胶水会溢出一些，我是将浸湿酒精的无尘布裹在镊子头部擦掉它们的，你也可以自由发挥。  

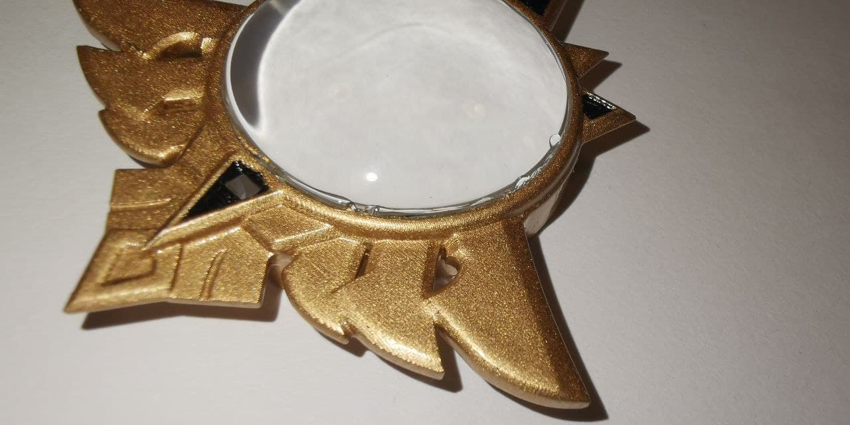
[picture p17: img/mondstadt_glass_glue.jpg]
  

清理好溢出的胶水后，再次确认玻璃水平，使用美纹纸胶带将玻璃与外壳固定。我选择的这个胶水的固化大概需要一至两天，固化后暂时还没遇到过强度问题。  

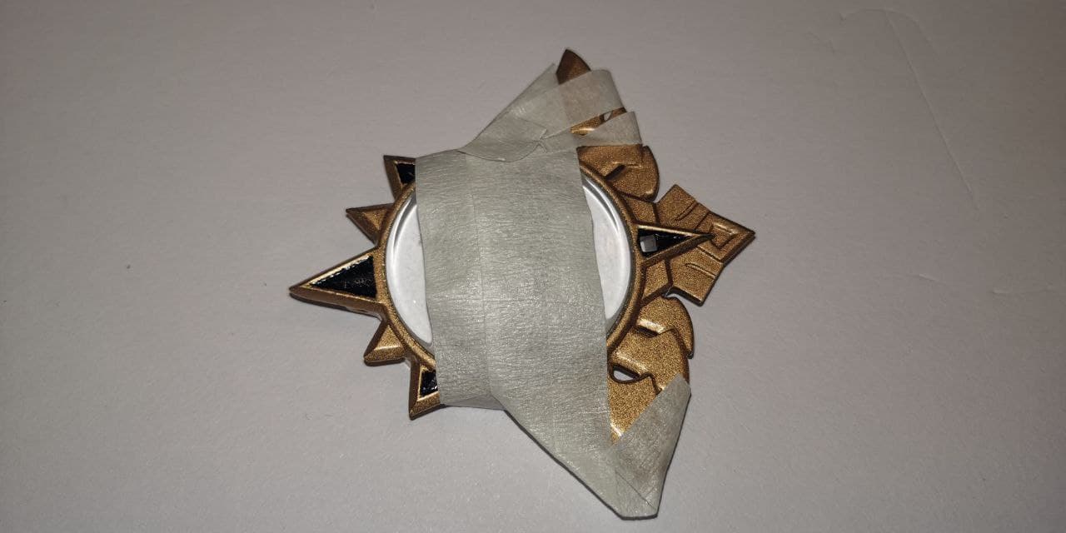
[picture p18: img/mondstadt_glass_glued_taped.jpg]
  

### 安装环境光传感器  
准备一个 TEMT6000X01 环境光传感器，一条上表中提到的排线和胶水。  
将传感器如下图所示焊接在排线的引脚上。你可能需要像图上那样记录下引脚关系。  

  

然后小心地将传感器所在位置折弯 90° 如下：  

  

在外壳的对应孔位挤一点胶水，并将传感器粘到孔中。  

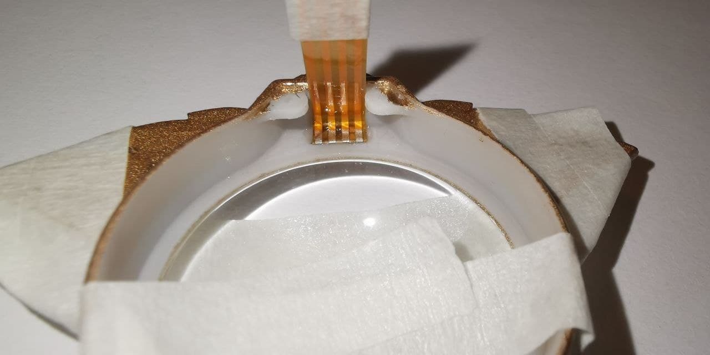
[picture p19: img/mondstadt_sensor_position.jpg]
  

使用美纹胶固定好传感器，等待胶水固化。  

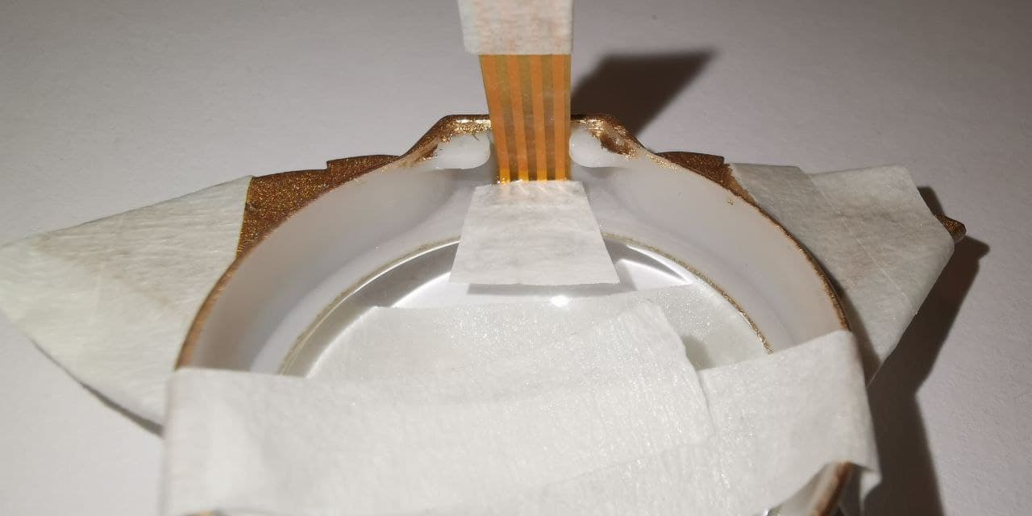
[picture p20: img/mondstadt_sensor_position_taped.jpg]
  

这时从外壳的正面应该可以正好露出传感器接收光线的部分。再在黑色部分均匀地覆盖一层胶水，同时作为固定和保护：  

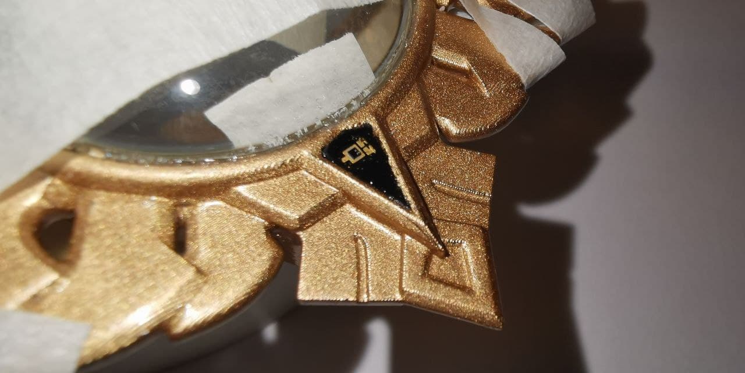
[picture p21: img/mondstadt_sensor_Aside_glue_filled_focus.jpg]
  

至此你已完成了外壳主体部分的组装。在等待两天胶水固化后即可拆除所有胶带。  

### 安装电路  
这一节的部分图片基于早期版本的电路和外壳，然后因为又懒又鸽导致还没更新，所以可能和实际的最新版本看上去不太一样。请动动脑  

你可以选择在安装电路板前先刷写固件。刷固件指引见 [/src](https://github.com/libc0607/esp32-vision/tree/main/src) 目录下，根据你的需要选择固件。  

将焊接好的电路板背面贴一层随便什么绝缘且最好导热好一点的东西，防止屏幕背板接触到电路板背面的触电造成短路：  
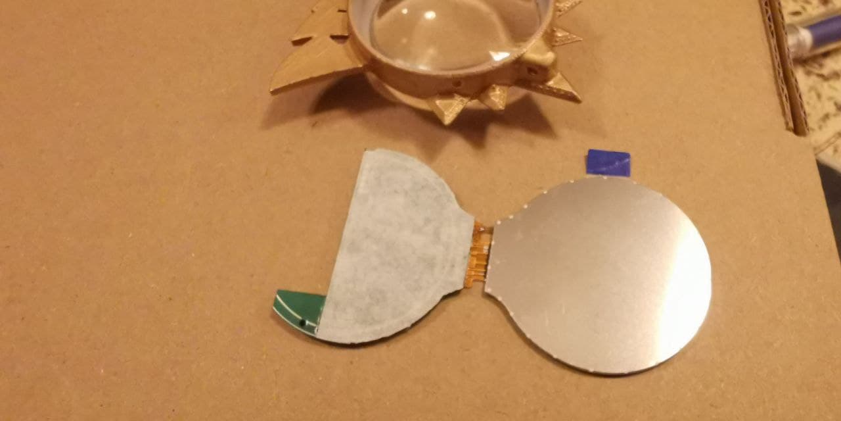
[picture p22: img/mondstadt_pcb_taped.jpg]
   
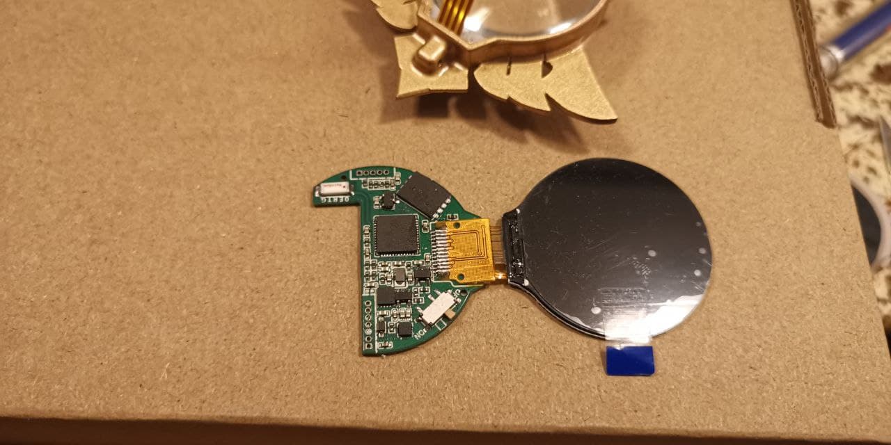
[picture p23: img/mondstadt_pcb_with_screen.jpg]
  

按照引脚定义焊接好：环境光传感器的 2 条线；无线充电模块 2 条线；电池和 NTC 电阻共 3 条线（共用 GND）。    
如果发现原配的导线较硬，导致难以装配，可以将你不喜欢的线换成材料清单中提到的耳机线，将外皮剥掉使用线芯。  

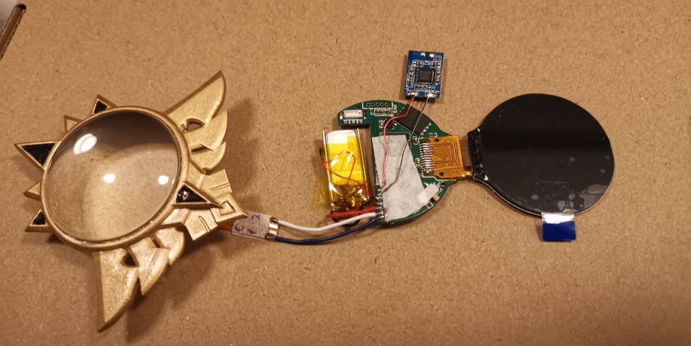
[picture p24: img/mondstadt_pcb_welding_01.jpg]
   

无线充电的线圈通过随便什么耐热的胶粘在后盖上，并在上面贴一层铁氧体隔磁片。钱多的同学也可以使用纳米晶隔磁片。  
然后在电路板的元件那面上再贴一小片隔磁片，将无线充电模块隔着这层隔磁片粘在电路板的上方附近。这一步没图，忘了拍了  

V3.3 版本在侧面增加了一个按键，需要将按键塞进按键孔后再放入屏幕和电路板，像这样：  

  

尝试按动，能够按下能够回弹即可。在铆钉上套一个 O 型圈可以让它的手感更好一点，不过没有的话影响也不大。  

最后就是像往肚子里塞肠子那样把它们都塞进去，只要能盖得上后盖，拧得上螺丝，就成功了（（  



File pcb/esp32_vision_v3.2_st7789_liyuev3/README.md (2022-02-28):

[OSHWHub: libc0607/esp32_vision_v3-2_liyuev3_st7789_rel](https://oshwhub.com/libc0607/esp32_vision_v3-2_liyuev3_st7789_rel)

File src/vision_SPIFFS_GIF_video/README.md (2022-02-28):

# vision_SPIFFS_GIF_video
这里是 ESP32 Vision 的测试代码之一。  
如果你只是想要一个可以简单地显示元素图标或者野兽仙贝，且不需要经常更改显示内容的钥匙链，那这个 Demo 适合你。   

## 测试效果 


见 [Bilibili BV1Fr4y1z7yS: 下北泽元素力测试 - bcccc23333](https://www.bilibili.com/video/BV1Fr4y1z7yS)  

## 硬件
目前版本的代码可配合 [方版（ST7789）](https://oshwhub.com/libc0607/esp32_vision_v3-2_liyuev3_st7789_rel) 及 [圆版（GC9A01）](https://oshwhub.com/libc0607/esp32_vision_v3-2_gc9a01_rel) 硬件版本 V3.2 使用。  

这个例子没有使用到板上的 SD Nand 和那个 0402 封装的 NTC，如果你想用这个例子那就可以不焊。（SD Nand 一片也十多块呢x）    
这个例子通过修改代码的方式同时支持 方版（ST7789）和 圆版（GC9A01），修改方式见下文。  

## 功能
 - 上电后从 SPIFFS 读取 GIF 图片
 - 播放完成后进入深度睡眠
 - 通过双击唤醒或是定时器唤醒（代码中默认 30s），再播放一次 GIF 图片，如此循环
 - 如果电量低，它就不亮了 （？废话）
 - 每次唤醒时根据环境光强度调节屏幕亮度  

## 编译 & 上传  

1. 安装 Arduino  
2. 安装 [espressif/arduino-esp32](https://github.com/espressif/arduino-esp32)  （仅在 V1.0.6 下测试过；高版本和下面某个库的兼容不好）
3. 安装 [moononournation/Arduino_GFX](https://github.com/moononournation/Arduino_GFX)  
4. 安装 [bitbank2/JPEGDEC](https://github.com/bitbank2/JPEGDEC)  
5. 安装 [DFRobot/DFRobot_LIS](https://github.com/DFRobot/DFRobot_LIS)  
6. 安装 [me-no-dev/arduino-esp32fs-plugin](https://github.com/me-no-dev/arduino-esp32fs-plugin)  
7. 下载这坨源码，打开
8. 选择：ESP32 Dev Module, 240MHz CPU, 80MHz Flash, DIO, 4MB(32Mb), No OTA (1M APP/3M SPIFFS), PSRAM Disable  
9. 上传
10. 将你需要的 GIF 文件通过 ffmpeg 或是其他的什么方式转为 240x240 @15fps，命名为 loop.gif ，放入 Data 文件夹中；这里也提供了两个示例 GIF 
11. "ESP32 Sketch Data upload" 写入 SPIFFS
12. 重启，你就获得了一颗下北泽神之眼 

## 自定义配置 
代码中有几个可以配置的地方： 
```
#define GIF_FILENAME "/loop.gif"      // SPIFFS 中的动图名，要以 / 开头

#define DEEP_SLEEP_TIME_S   30        // 深度睡眠后，定时器唤醒的时间，单位是秒

#define BAT_ADC_THRESH_LOW  1700      // 低电压保护。当每一轮工作开始时，如果 ADC 读取到的电压读数低于这个值，就不会播放 GIF，直接进入下一轮睡眠
                                      // 由于 ESP32 的 ADC 质量不咋样，所以没有换算成电压。你可以根据自己板子的情况尝试调节这个值。  

//Arduino_GC9A01  *gfx = new Arduino_GC9A01(bus, PIN_TFT_RST, 2, true);
Arduino_ST7789  *gfx = new Arduino_ST7789(bus, PIN_TFT_RST, 0, true, 240, 240, 0, 0);
                                      // 在这里选择你的屏幕种类

```
## 参考 
[moononournation/RGB565_video](https://github.com/moononournation/RGB565_video)  
雷元素图标来自 [Bilibili: 鱼翅翅Kira](https://space.bilibili.com/2292091)

## 免责声明  
这段代码仅用作测试，由于滥用造成的一切不好的后果和作者无关。  
如果其中的图片素材涉及侵权，请联系我删除。

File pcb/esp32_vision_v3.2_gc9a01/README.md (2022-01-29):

[OSHWHub: libc0607/esp32_vision_v3-2_gc9a01_rel](https://oshwhub.com/libc0607/esp32_vision_v3-2_gc9a01_rel)

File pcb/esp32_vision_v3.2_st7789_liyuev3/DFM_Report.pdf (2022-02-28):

高效的pcb制造分析软件

检查报告 | 关注公众号

时间2022-02-08

文件名：Gerber_PCB_esp32- | 层数：4 | 尺寸：38.00*18.00 mm


## 警示项


报告项目 | 类型 | 分析结果 | 描述与建议


最小间距 | 盘到线 | 0.11479 mm | 您的“焊盘到线”最小间距为4.52mil，会影响生产效率、品质良率，可能会导 致费用上涨，建议“焊盘到线”最小间距≥6mil


最小间距 | 线到线 | 0.11479 mm | 您的“最小线距”为4.82mil，会影响生产效率、品质良率，可能会导致费用上 涨，建议“密集区域”线距≥4mil、“普通区域”线距≥6mil


最小线宽 | 最小线宽 | 0.12 mm | 您的“最小线宽”为4.72mil，会影响生产效率、品质良率，可能会导致费用上 涨，建议“密集区域”线宽≥3.5mil、“普通区域”线宽≥6mil


孔大小 | 厚径比 | 0.2 mm | 您的“最小厚径比”为8.00，会影响生产效率、品质良率，可能会导致费用上 涨，建议“最小厚径比”<8:1


孔大小 | 最小孔径 | 0.2 mm | 您的“最小孔径”为0.20mm，会影响生产效率、品质良率，可能会导致费用上 涨，建议“最小孔径”≥0.3mm


孔环 | 过孔孔环 | 有 | 您的“过孔孔环”最小为infmil会影响产品可靠性，建议“过孔孔环”最小环 ≥ 5 mil


孔到线 | 插件孔到内层 | 0.23987 mm | 您的内层“插件孔到线”最小间距为11.06mil，会影响生产效率、品质良率，可 能会导致费用上涨，建议内层“插件孔到线”最小间距≥12mil


孔到线 | 插件孔到表层 | 0.23987 mm | 您的外层“插件孔到线”最小间距为11.06mil，会影响生产效率、品质良率，可 能会导致费用上涨，建议外层“插件到线”最小间距≥12mil


孔到线 | 过孔到表层 | 0.23987 mm | 您的外层“过孔到线”最小间距为9.44mil，会影响生产效率、品质良率，可能 会导致费用上涨，建议内层“过孔到线”最小间距≥10mil


孔上焊盘 | 过孔上焊盘 | 有 | 您的“设计”存在“孔在SMD焊盘上”，会影响焊盘的平整度，可能会导致焊 锡不良。

# 全部检查项

报告项目 | 类型 | 分析结果

电气信号 开短路 | 断头线 | 正常
| 孤立铜 | 正常
| 无效过孔 | 正常
| 片式SMD没连线路 | 正常
| 锐角 | 正常
最小线宽 | 最小线宽 | 6pis 0.12 mm
最小间距 | 线到线 | 62pis 0.11479 mm
| 盘到线 | 138pis 0.11479 mm
| 盘到盘 | 正常 0.11479 mm
最小焊盘 | BGA焊盘 | 正常
| 常规焊盘 | 正常
| 长条焊盘 | 正常 >0.25 mm
SMD间距 | 同网络SMD焊盘间距 | 正常 0.21987 mm
| 不同网络SMD焊盘间 距 | 正常 0.21987 mm
| 同器件焊盘间距 | 正常
| 不同器件焊盘间距 | 正常
网格铺铜 | 网格线宽 | 正常
| 网格线距 | 正常
孔大小 | 最小孔径 | 4pis 0.2 mm
| 最大孔径 | 正常
| 厚径比 | 1pis 0.2 mm
槽孔 | 最小槽宽 | 正常
| 最大槽宽 | 正常
| 槽长宽比 | 正常

孔环 | 过孔孔环 | 256pis 有
| 插件孔孔环 | 正常
孔到孔 | 同网络过孔 | 正常 0.25 mm
| 不同网络过孔 | 正常
| 插件孔 | 正常
孔到线 | 过孔到表层 | 94pis 0.23987 mm
| 插件孔到表层 | 5pis 0.23987 mm
| 过孔到内层 | 正常 0.23987 mm
| 插件孔到内层 | 2pis 0.23987 mm
| NPTH到铜 | 正常
板边距离 | 铜/PAD/线到板边距 离 | 正常
| SMD到板边距离 | 正常
| 孔到板边 | 正常
特殊孔 | 半孔 | 正常
| 盲埋孔 | 正常
| 盲埋孔距离 | 正常
| 激光孔 | 正常
| 正/长方形孔 | 正常
焊盘规格 | 焊盘大小异常 | 正常
| 封装内间距异常 | 正常
孔上焊盘 | 盘中孔 | 正常
| 插件孔 | 正常
| 过孔上焊盘 | 1pis 有
| 非金属孔 | 正常

阻焊开窗 | 阻焊异常 | 正常
| 阻焊盖线 | 正常
| 阻焊间隙 | 正常
| 同网络阻焊间隙 | 正常
| 漏阻焊桥 | 正常
| 同网络漏阻焊桥 | 正常
孔密度 | 孔密度 | 179个；26.17万/m²
沉金面积 | 沉金面积 | 30.55%
飞针点数 | 飞针点数 | 213
Mark点 | Mark点 | 正常
锣长分析 | 锣长分析 | 168.628m/㎡

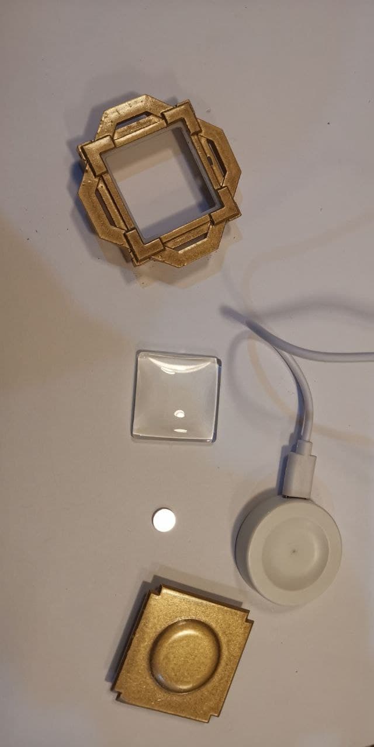
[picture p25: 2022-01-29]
img/liyue_glass_charger.jpg

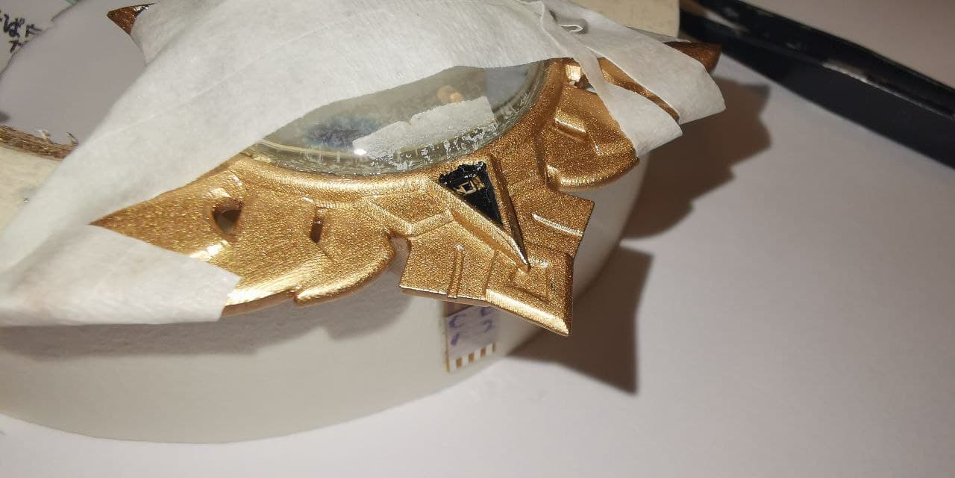
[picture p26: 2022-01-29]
img/mondstadt_sensor_Aside_glue_filled.jpg

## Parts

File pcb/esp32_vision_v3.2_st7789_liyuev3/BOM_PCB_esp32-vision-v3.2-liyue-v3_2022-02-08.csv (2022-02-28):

ID | Name | Designator | Footprint | Quantity | Manufacturer Part | Manufacturer | Supplier | Supplier Part | Price
1 | 1uF | C6 | C0402 | 1 | CL05A105KA5NQNC | SAMSUNG | LCSC | C52923 | 0.0211
2 | 3.3kΩ | R19 | R0402 | 1 | 0402WGF3301TCE | UniOhm | LCSC | C25890 | 0.0038
3 | 10uF | C1,C2,C4,C5,C8,C9,C10,C11,C13,C14,C15,C16,C17 | C0402 | 13 | CL05A106MQ5NUNC | SAMSUNG | LCSC | C15525 | 0.0312
4 | 4.7uF | C7 | C0402 | 1 | CL05A475MP5NRNC | SAMSUNG | LCSC | C23733 | 0.0361
5 | 100nF | C20 | C0402 | 1 | CL05B104KB54PNC | Samsung Electro-Mechanics | LCSC | C307331 | 0.039
6 | 100nF | C3,C12,C21 | C0402_NEW | 3 | CL05B104KO5NNNC | SAMSUNG | LCSC | C1525 | 0.0068
7 | A1251WV-5P | CN1,CN2 | CONN-TH_5P-P1.25_A1251WV-5P | 2 | A1251WV-5P | Changjiang Connectors | LCSC | C225093 | 0.6765
8 | 1N5819WS | D1 | SOD-323_L1.8-W1.3-LS2.5-RD | 1 | 1N5819WS | Guangdong Hottech | LCSC | C191023 | 0.1986
9 | AN2051-245 | L1 | ANT2051 | 1 | AN2051-245 | Rainsun | LCSC | C99727 | 49.05
10 | 2.2uH | L3 | L0806 | 1 | DFE201612E-2R2M=P2 | Murata Electronics | LCSC | C337893 | 1.0569
11 | AO3400A | Q2 | SOT-23-3_L2.9-W1.6-P1.90-LS2.8-BR | 1 | AO3400A | AOS | LCSC | C20917 | 0.9865
12 | 100K | R1 | R0402 | 1 | 0402WGF1003TCE | UniOhm | LCSC | C25741 | 0.0044
13 | 3.9K | R2,R6 | R0402 | 2 | 0402WGF3901TCE | UniOhm | LCSC | C51721 | 0.0047
14 | 10K | R3,R5 | R0402 | 2 | 0402WGF1002TCE | UniOhm | LCSC | C25744 | 0.0035
15 | 10 | R4 | R0402 | 1 | 0402WGF100JTCE | UniOhm | LCSC | C25077 | 0.0038
16 | 20K | R7,R17 | R0402 | 2 | 0402WGF2002TCE | UniOhm | LCSC | C25765 | 0.0039
17 | 10kΩ | R8 | R0402 | 1 | NTCG104BH103JT1 | TDK | LCSC | C92039 | 0.3362
18 | 15K | R9 | R0402 | 1 | 0402WGF1502TCE | UniOhm | LCSC | C25756 | 0.004
19 | 1M | R10,R11,R14,R18 | R0402 | 4 | 0402WGF1004TCE | UniOhm | LCSC | C26083 | 0.0042
20 | 2M | R13 | R0402 | 1 | 0402WGF2004TCE | UniOhm | LCSC | C11512 | 0.0057
21 | 100 | R15,R16 | R0402 | 2 | 0402WGF1000TCE | UniOhm | LCSC | C25076 | 0.0037
22 | MSK12C02 | SW1 | SW-TH_MSK12C02 | 1 | MSK12C02 | SHOU HAN | LCSC | C431540 | 0.3189
23 | ESP32-PICO-D4 | U1 | QFN-48_L7.0-W7.0-P0.50-BL-EP5.4 | 1 | ESP32-PICO-D4 | Espressif Systems | LCSC | C193707 | 22.9
24 | SY6280AAC | U3 | SOT-23-5_L3.0-W1.7-P0.95-LS2.8-BR | 1 | SY6280AAC | Silergy | LCSC | C55136 | 1.7091
25 | ETA3425S2F | U4 | SOT-23-5_L2.9-W1.6-P0.95-LS2.8-BL | 1 | ETA3425S2F | null | LCSC | C2890147
26 | CSNP1GCR01-BOW | U5 | LGA-8_L6.0-W8.0-P1.27-TL | 1 | CSNP1GCR01-BOW | CS(创世) | LCSC | C2691593 | 15.78
27 | CN3165 | U7 | DFN-8_L3.0-W3.0-P0.50-TL-EP | 1 | CN3165 | ShangHai Consonance Elec | LCSC | C559035 | 2.63
28 | LIS2DH12TR | U8 | LGA-12_L2.0-W2.0-P0.50-BL | 1 | LIS2DH12TR | STMicroelectronics | LCSC | C110926 | 6.47
29 | 1.25T-2A_C722633 | CN3 | CONN-TH_1.25T-2A_1.25T-2A | 1 | 1.25T-2A | CAX(创都) | LCSC | C722633 | 0.0407
30 | ST7789-1.54寸 | U2 | ST7789-1.54寸 | 1

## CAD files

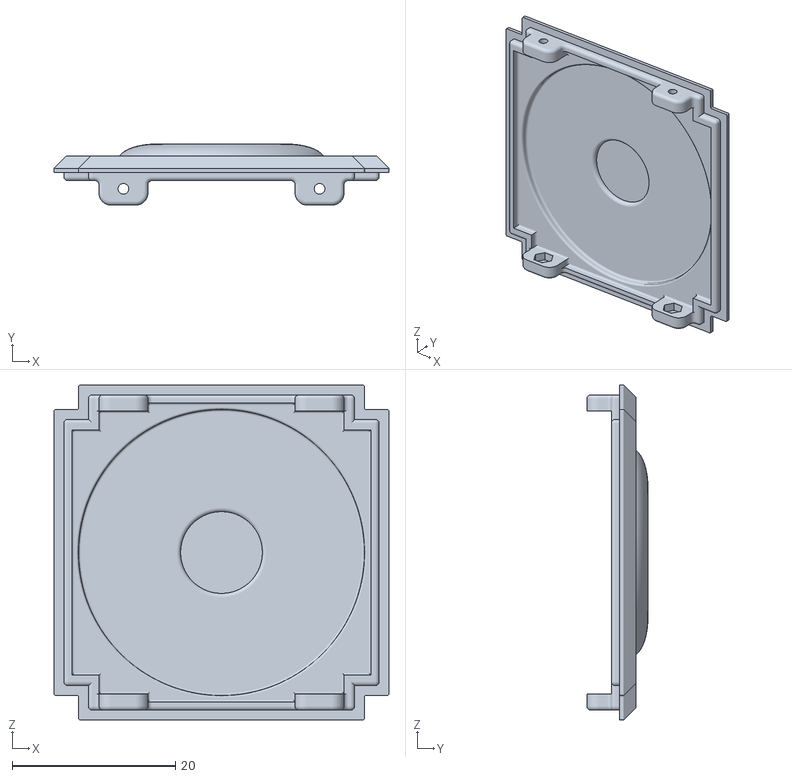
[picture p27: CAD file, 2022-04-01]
stl/liyue/liyue-v2.2-cap.STL
41.0 x 7.50 x 41.0

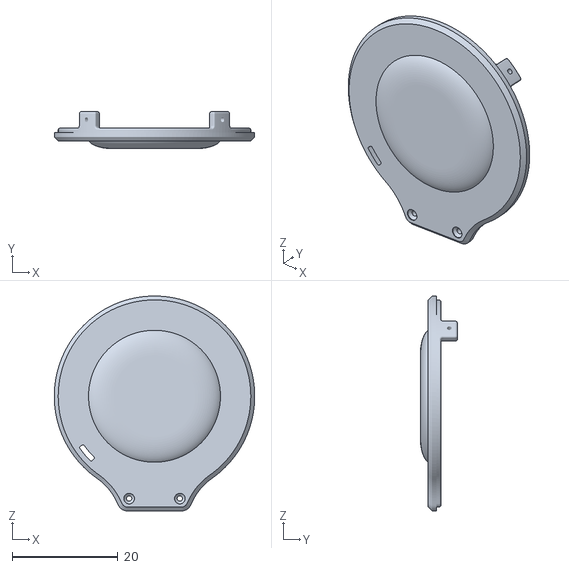
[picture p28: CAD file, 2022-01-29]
stl/mondstadt/mondstadt-cap-v2.1.STL
38.0 x 7.10 x 40.7

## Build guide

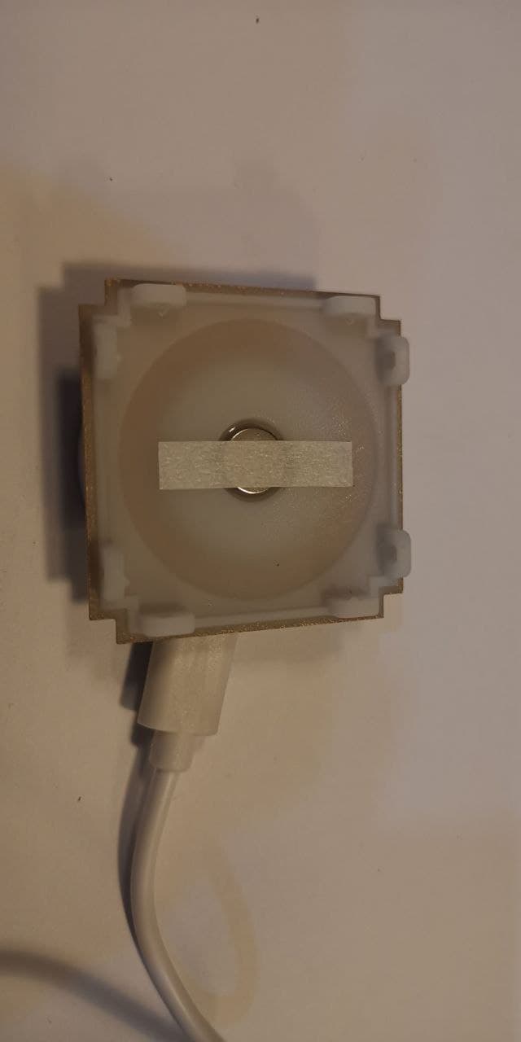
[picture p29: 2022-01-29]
img/liyue_charger_install_taped.jpg

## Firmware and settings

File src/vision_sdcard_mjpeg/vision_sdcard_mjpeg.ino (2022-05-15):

/*
   Vision V3.3 SD MJPEG WebServer OTA BLE DEMO
   Github: libc0607/esp32-vision

   ref:
   https://github.com/moononournation/RGB565_video 
   examples/SDWebServer
   examples/OTAWebUpdater

   WebServer bring-up:
   curl -X POST -F "file=@ota.htm" http://vision.local/edit
   curl -X POST -F "file=@index.htm" http://vision.local/edit
   curl -X POST -F "file=@edit.htm" http://vision.local/edit

   How-to in Arduino IDE:
    Choose:
      ESP32 Dev Module, 240MHz CPU, 80MHz Flash, DIO, 4MB(32Mb),
      Minimal SPIFFS (1.9MB with OTA/190kB SPIFFS), PSRAM Disable;
    upload;

   Dependencies:
     Install espressif/arduino-esp32 (V1.0.6, due to compatibility issue) first
     moononournation/Arduino_GFX
     bitbank2/JPEGDEC
     DFRobot/DFRobot_LIS (see tapInterrupt example)
     stevemarple/IniFile

   Config ini example:

    [vision]
    video=/loop.mjpeg
    lcd_rotation=0
    loop_mode=false
    abloop_en=false
    ble_mac=00:12:34:56:78:9a
    
   There are 3 working modes:
    a. Loop video A or B, controlled by iTag or double tap;
      you should: 
        set loop_mode = true
        set abloop_en = true
        if u have an iTag, set ble_mac to your iTag MAC address; else, delete ble_mac  
        upload /a_setup.mjpeg, /a_loop.mjpeg, /b_setup.mjpeg, /b_loop.mjpeg
    b. Loop one video;
      u should:
        upload video (e.g. hydro.mjpeg)
        set loop_mode = true
        set abloop_en = false
        set video = hydro.mjpeg
    c. play video once, then deep sleep; wakeup by double tap;
      u should:
        upload video (e.g. hydro.mjpeg)
        set loop_mode = false
        set video = hydro.mjpeg
        
   This is just an EARLY DEMO to verify all parts of the
   hardware can work properly.
   Many bugs. No guarantee for the performance of this code.
   就是抄了一大堆例程，并小心地让它们能一起工作而已。很烂，轻喷

*/
#define CONFIG_FILENAME "/config.txt"
const char* wifi_ssid = "Celestia";
const char* wifi_pwd = "mimitomo";
const char* wifi_host = "vision";
#define CONF_GIFNAME_DEFAULT "/loop.mjpeg"
#define CONF_TARGET_FPS_DEFAULT 15
//#define CONF_GRAVITY_DEFAULT  true
#define CONF_LCD_ROTATION_DEFAULT  0
#define CONF_LOOP_MODE_DEFAULT true
#define DEEP_SLEEP_LONG_S  30
#define DEEP_SLEEP_SHORT_S  2
#define DEEP_SLEEP_SHORT_CNT  6
#define TEMP_PROTECT_HIGH_THRESH_12B  1840 // ~60°C @10k,B3380
#define LCD_BACKLIGHT_MIN_12B  640
#define LCD_PWM_FIR_LEN 32
#define LCD_PWM_CHANGE_MAX_STEP 32
#define VIDEO_A_SETUP   "/a_setup.mjpeg"
#define VIDEO_B_SETUP   "/b_setup.mjpeg"
#define VIDEO_A_LOOP    "/a_loop.mjpeg"
#define VIDEO_B_LOOP    "/b_loop.mjpeg"
#define LOCK_SCREEN_TIME_THRESH_MS 1000
#define BL_LEVEL_MAX 4095

#define FILE_SYSTEM  SD

#include <WiFi.h>
#include <WiFiClient.h>
#include <WiFiAP.h>
#include <WebServer.h>
#include <SPI.h>
#include <SD.h>
#include <SD_MMC.h>
#include <ESPmDNS.h>
#include <DFRobot_LIS.h>
#include <DFRobot_LIS2DW12.h>
#include <IniFile.h>
#include <Update.h>
#include <SPIFFS.h>
#include <Arduino_GFX_Library.h>
#include <Wire.h>
#include <esp_sleep.h>
#include <rom/rtc.h>
#include <driver/rtc_io.h>
#include <driver/adc.h>
#include <esp_wifi.h>
#include "BLEDevice.h"


#define PIN_MISO        2     // sdcard
#define PIN_SCK         14    // sdcard
#define PIN_MOSI        15    // sdcard
#define PIN_SD_CS       13    // sdcard
#define PIN_TFT_CS      5     // LCD
#define PIN_TFT_BL      22    // LCD
#define PIN_TFT_DC      27    // LCD
#define PIN_TFT_RST     33    // LCD
#define PIN_LCD_PWR_EN  19    // LCD, SDcard & temt6000 3v3 power (SY6280AAC on board)
#define PIN_ADC_BAT     35    // battery voltage, with 1M/1M resistor dividor on hardware
#define PIN_TEMP_ADC    36    // 
#define PIN_BAT_STDBY   37    // cn3165 standby, low == charge finish, ext. pull-up
#define PIN_BAT_CHRG    38    // cn3165 chrg, low == charging, ext. pull-up
#define PIN_ACC_INT1    39    // from accelerometer, push-pull
#define PIN_ACC_INT2    32    // not used
#define PIN_SENSOR_ADC  34    // light sensor (temt6000), to GND if not connected
#define PIN_I2C_SCL     25    // to accelerometer
#define PIN_I2C_SDA     26    // to accelerometer
#define PIN_LED         23    // ext. led
#define PIN_KEY         18    // ext. key

#define WIFI_CONNECT_TIMEOUT_S 20
#define uS_TO_S_FACTOR (1000000ULL)
//#define BAT_ADC_THRESH_LOW   (1700)  // analogRead( 1/2*Vbat )
#define BAT_ADC_THRESH_LOW_MV   (2900)  // analogReadMilliVolts(Vbat)
//#define BAT_ADC_THRESH_WARN  (1880)  // analogRead( 1/2*Vbat )
#define MJPEG_BUFFER_SIZE (240 * 240 * 2 / 4)

Arduino_DataBus *bus = new Arduino_ESP32SPI(PIN_TFT_DC/* DC */, PIN_TFT_CS /* CS */, PIN_SCK, PIN_MOSI, PIN_MISO, VSPI, true );
Arduino_ST7789  *gfx = new Arduino_ST7789(bus, PIN_TFT_RST, 0, true, 240, 240, 0, 0, 0, 80);
//Arduino_GC9A01  *gfx = new Arduino_GC9A01(bus, PIN_TFT_RST, 2, true); 

DFRobot_LIS2DW12_I2C acce(&Wire, 0x19);   // sdo/sa0 internal pull-up

#include "MjpegClass.h"
static MjpegClass mjpeg;
uint8_t *mjpeg_buf;

unsigned long lightsleep_ms;
TaskHandle_t LCD_BL_TaskHandle;
xQueueHandle lcd_bl_queue;

WebServer server(80);
static bool hasSD = false;
File uploadFile;
int led_status;

RTC_DATA_ATTR int bootCount = 0;
RTC_DATA_ATTR int lastTappedCount = 0;

/*  BLE Connection to iTag. 
 *   
 *  BUG: cause reset when connect itag at the second time, and i don't know why 
 *       however the first connection is ok, if u keep that connection it's still usable
 *       
 *  This bunch of sh*t logic is designed to smoothly switching 
 *  between two video parts A & B when BLE got notified
 *  
 *  to enable this feature, you need 4 pieces of video:
 *  Length:     |--------------|--------------|--------------|--------------|
 *  Part:       |   A setup    |    A Loop    |   B Setup    |   B Loop     |  
 *  
 *  the BLE part: i just copied his code, no optimization
 *  See http://100-x-arduino.blogspot.com/2018/05/itag-i-arduino-ide-czy-esp32-otworzy.html
 *  
 *  About how to fix the memory leak of the iTag example, see
 *    https://github.com/nkolban/esp32-snippets/issues/1006
 *    https://github.com/nkolban/esp32-snippets/issues/786
 *    
*/
static BLEUUID serviceUUID("0000ffe0-0000-1000-8000-00805f9b34fb");
static BLEUUID charUUID("0000ffe1-0000-1000-8000-00805f9b34fb"); 
static BLEAddress *pServerAddress;
static boolean ble_doconnect = false;
static boolean ble_connected = false;
static BLERemoteCharacteristic* pRemoteCharacteristic;
static BLEClient* pClient;
bool deviceBleConnected = false;
bool ble_key_pressed = false;   // when ble got notify
TaskHandle_t BLE_TaskHandle;

// led indicator
TaskHandle_t LED_TaskHandle;
xQueueHandle led_queue;

class MyClientCallbacks: public BLEClientCallbacks {
    void onConnect(BLEClient *pClient) {
      deviceBleConnected = true;
      Serial.println("BLE: connected to my server");
    };
    void onDisconnect(BLEClient *pClient) {
      pClient->disconnect();
      deviceBleConnected = false;
      Serial.println("BLE: disconnected from my server");
      ble_connected = false;
    }
};

MyClientCallbacks* callbacks = new MyClientCallbacks();

static void notifyCallback(
  BLERemoteCharacteristic* pBLERemoteCharacteristic,
  uint8_t* pData, size_t length, bool isNotify) {
  Serial.println("BLE: Notify from iTAG");  
  ble_key_pressed = true;
}

bool connectToServer(BLEAddress pAddress) {
  if (pClient != nullptr) {
    delete(pClient);
  }
  pClient = BLEDevice::createClient();  
  pClient->setClientCallbacks(callbacks); 
  pClient->connect(pAddress); 
  if (!pClient->isConnected())
    return false;
  BLERemoteService* pRemoteService = pClient->getService(serviceUUID); 
  if (pRemoteService == nullptr) {
    Serial.print("BLE: Failed to find our service UUID ");    
    return false;
  }
  Serial.println("BLE: Found service " + String(pRemoteService->toString().c_str())); 

  pRemoteCharacteristic = pRemoteService->getCharacteristic(charUUID);
  if (pRemoteCharacteristic == nullptr) {
    Serial.println("BLE: Failed to find our characteristic UUID ");    
    return false;
  }
  Serial.println("BLE: Found characteristic" + String(pRemoteCharacteristic->toString().c_str()));

  //std::string value = pRemoteCharacteristic->readValue();
  //Serial.print("BLE: Read characteristic value: ");  Serial.println(value.c_str());

  //const uint8_t bothOff[]        = {0x0, 0x0};
  const uint8_t notificationOn[] = {0x1, 0x0};
  //const uint8_t indicationOn[]   = {0x2, 0x0};
  //const uint8_t bothOn[]         = {0x3, 0x0};

  pRemoteCharacteristic->getDescriptor(BLEUUID((uint16_t)0x2902))->writeValue((uint8_t*)notificationOn, 2, true); 
  Serial.println("BLE: Notification ON ");
  pRemoteCharacteristic->registerForNotify(notifyCallback); // Callback function when notification
  Serial.println("BLE: Notification Callback ");
  return true;
}

// pixel drawing callback
static int drawMCU(JPEGDRAW *pDraw) {
  // Serial.printf("Draw pos = %d,%d. size = %d x %d\n", pDraw->x, pDraw->y, pDraw->iWidth, pDraw->iHeight);
  gfx->draw16bitBeRGBBitmap(pDraw->x, pDraw->y, pDraw->pPixels, pDraw->iWidth, pDraw->iHeight);
  return 1;
} /* drawMCU() */

void set_io_before_deep_sleep() {

  pinMode(PIN_TFT_BL, INPUT);
  pinMode(PIN_TFT_CS, INPUT);
  pinMode(PIN_TFT_RST, INPUT);
  pinMode(PIN_MISO, INPUT);
  pinMode(PIN_SCK, INPUT);
  pinMode(PIN_MOSI, INPUT);
  pinMode(PIN_SD_CS, INPUT);
  pinMode(PIN_TFT_DC, INPUT);
  pinMode(1, INPUT);
  pinMode(3, INPUT);
  pinMode(PIN_I2C_SCL, INPUT);
  pinMode(PIN_I2C_SDA, INPUT);
  pinMode(PIN_ACC_INT2, INPUT);
  pinMode(PIN_ADC_BAT, INPUT);
  pinMode(PIN_TEMP_ADC, INPUT);
  pinMode(PIN_SENSOR_ADC, INPUT);

  pinMode(PIN_ACC_INT1, INPUT);
  pinMode(PIN_BAT_STDBY, INPUT);
  pinMode(PIN_BAT_CHRG, INPUT);

  pinMode(PIN_KEY, INPUT_PULLUP);
  pinMode(PIN_LED, INPUT);
  
  esp_sleep_enable_ext0_wakeup((gpio_num_t)PIN_ACC_INT1 , HIGH);
  //esp_sleep_enable_ext0_wakeup((gpio_num_t)PIN_BAT_STDBY , LOW);
  //esp_sleep_enable_ext0_wakeup((gpio_num_t)PIN_BAT_CHRG , LOW);
  
  digitalWrite(PIN_LCD_PWR_EN, LOW);
  gpio_hold_en(( gpio_num_t ) PIN_LCD_PWR_EN );
  gpio_deep_sleep_hold_en();
  esp_wifi_stop();
  //adc_power_release();
}

void returnOK() {
  server.send(200, "text/plain", "");
}

void returnFail(String msg) {
  server.send(500, "text/plain", msg + "\r\n");
}

bool loadFromSdCard(String path) {
  //bool is_gzipped = false;
  
  String dataType = "text/plain";
  if (path.endsWith("/")) {
    path += "index.htm";
  }

  if (path.endsWith(".src")) {
    path = path.substring(0, path.lastIndexOf("."));
  } else if (path.endsWith(".htm")) {
    dataType = "text/html";
  } else if (path.endsWith(".css")) {
    dataType = "text/css";
  } else if (path.endsWith(".js")) {
    dataType = "application/javascript";
  } else if (path.endsWith(".png")) {
    dataType = "image/png";
  } else if (path.endsWith(".gif")) {
    dataType = "image/gif";
  } else if (path.endsWith(".jpg")) {
    dataType = "image/jpeg";
  } else if (path.endsWith(".ico")) {
    dataType = "image/x-icon";
  } else if (path.endsWith(".xml")) {
    dataType = "text/xml";
  } else if (path.endsWith(".pdf")) {
    dataType = "application/pdf";
  } else if (path.endsWith(".zip")) {
    dataType = "application/zip";
  }

  File dataFile = FILE_SYSTEM.open(path.c_str());
  if (dataFile.isDirectory()) {
    path += "/index.htm";
    dataType = "text/html";
    dataFile = FILE_SYSTEM.open(path.c_str());
  }

  if (!dataFile) {
    return false;
  }

  if (server.hasArg("download")) {
    dataType = "application/octet-stream";
  }

  // for ffmpeg.wasm
  // 试过了 这不太现实 并且太慢 算了
  //server.sendHeader("Cross-Origin-Opener-Policy", "same-origin");
  //server.sendHeader("Cross-Origin-Embedder-Policy", "require-corp");
  
  if (server.streamFile(dataFile, dataType) != dataFile.size()) {
    Serial.println("Sent less data than expected!");
  }

  dataFile.close();
  return true;
}

void handleFileUpload() {
  if (server.uri() != "/edit") {
    return;
  }
  HTTPUpload& upload = server.upload();
  String filename = upload.filename;
  if (!filename.startsWith("/"))
    filename = "/" + filename;
  if (upload.status == UPLOAD_FILE_START) {
    gfx->fillScreen(ORANGE);SD.begin(PIN_SD_CS);
    if (FILE_SYSTEM.exists(filename)) {
      FILE_SYSTEM.remove(filename);
    }
    uploadFile = FILE_SYSTEM.open(filename, FILE_WRITE);
    Serial.print("Upload: START, filename: "); Serial.println(filename);
  } else if (upload.status == UPLOAD_FILE_WRITE) {
    led_status = (led_status == HIGH)? LOW: HIGH;
    digitalWrite(PIN_LED, led_status);
    if (uploadFile) {
      uploadFile.write(upload.buf, upload.currentSize);
    }
    Serial.print("Upload: WRITE, Bytes: "); Serial.println(upload.currentSize);
  } else if (upload.status == UPLOAD_FILE_END) {
    if (uploadFile) {
      uploadFile.close();
    }
    gfx->fillScreen(BLUE);SD.begin(PIN_SD_CS);
    Serial.print("Upload: END, Size: "); Serial.println(upload.totalSize);
  }
}

void deleteRecursive(String path) {
  File file = FILE_SYSTEM.open((char *)path.c_str());
  if (!file.isDirectory()) {
    file.close();
    FILE_SYSTEM.remove((char *)path.c_str());
    return;
  }

  file.rewindDirectory();
  while (true) {
    File entry = file.openNextFile();
    if (!entry) {
      break;
    }
    String entryPath = path + "/" + entry.name();
    if (entry.isDirectory()) {
      entry.close();
      deleteRecursive(entryPath);
    } else {
      entry.close();
      FILE_SYSTEM.remove((char *)entryPath.c_str());
    }
    yield();
  }

  FILE_SYSTEM.rmdir((char *)path.c_str());
  file.close();
}

void handleDelete() {
  if (server.args() == 0) {
    return returnFail("BAD ARGS");
  }
  String path = server.arg(0);
  if (path == "/" || !FILE_SYSTEM.exists((char *)path.c_str())) {
    returnFail("BAD PATH");
    return;
  }
  deleteRecursive(path);
  returnOK();
}

void handleCreate() {
  if (server.args() == 0) {
    return returnFail("BAD ARGS");
  }
  String path = server.arg(0);
  if (path == "/" || FILE_SYSTEM.exists((char *)path.c_str())) {
    returnFail("BAD PATH");
    return;
  }

  if (path.indexOf('.') > 0) {
    File file = FILE_SYSTEM.open((char *)path.c_str(), FILE_WRITE);
    if (file) {
      file.write(0);
      file.close();
    }
  } else {
    FILE_SYSTEM.mkdir((char *)path.c_str());
  }
  returnOK();
}

void getStatus() {

  // A human-readable system status API

  String stat = "";

  // card type
  //stat += "SD_Type,";
  uint8_t cardType = FILE_SYSTEM.cardType();
  if (cardType == CARD_NONE) {
    stat += "No_Card";
  } else if (cardType == CARD_MMC) {
    stat += "SD_MMC";
  } else if (cardType == CARD_SD) {
    stat += "SD_SC";
  } else if (cardType == CARD_SDHC) {
    stat += "SD_HC";
  } else {
    stat += "Card_UNKNOWN";
  }
  stat += ", ";

  // card space
  stat += String(int(FILE_SYSTEM.usedBytes() / (1024 * 1024))); 
  stat += "MB/";
  stat += String(int(FILE_SYSTEM.totalBytes() / (1024 * 1024)));
  stat += "MB, ";
  // Battery info
  //stat += "Battery_ADC,";
  //stat += analogRead(PIN_ADC_BAT);
  stat += (2*analogReadMilliVolts(PIN_ADC_BAT)); stat += "mV";
  //stat += ",Charger,";
  stat += ", ";
  if (digitalRead(PIN_BAT_CHRG) == LOW) {
    stat += "Charging, ";
  } else if (digitalRead(PIN_BAT_STDBY) == LOW) {
    stat += "Full, ";
  } else {
    stat += "NotCharging, ";
  }

  // light sensor info
  //stat += "Light_ADC,";
  stat += analogRead(PIN_SENSOR_ADC);
  stat += "/4095, ";
  
  // acce.
  stat += "X, ";
  stat += acce.readAccX();
  stat += "mg, Y, ";
  stat += acce.readAccY();
  stat += "mg, Z, ";
  stat += acce.readAccZ();
  stat += "mg, ";
  
  // firmware info
  stat += __DATE__ ;
  stat += " ";
  stat += __TIME__ ; 
  stat += "\r\n";
  server.send(200, "text/plain", stat);
}

void printDirectory() {
  if (!server.hasArg("dir")) {
    return returnFail("BAD ARGS");
  }
  String path = server.arg("dir");
  //if (path != "/" && !SD.exists((char *)path.c_str())) {
  if (path != "/" && !FILE_SYSTEM.exists((char *)path.c_str())) {
    return returnFail("BAD PATH");
  }
  //File dir = SD.open((char *)path.c_str());
  File dir = FILE_SYSTEM.open((char *)path.c_str());
  path = String();
  if (!dir.isDirectory()) {
    dir.close();
    return returnFail("NOT DIR");
  }
  dir.rewindDirectory();
  server.setContentLength(CONTENT_LENGTH_UNKNOWN);
  server.send(200, "text/json", "");
  WiFiClient client = server.client();

  server.sendContent("[");
  for (int cnt = 0; true; ++cnt) {
    File entry = dir.openNextFile();
    if (!entry) {
      break;
    }

    String output;
    if (cnt > 0) {
      output = ',';
    }

    output += "{\"type\":\"";
    output += (entry.isDirectory()) ? "dir" : "file";
    output += "\",\"name\":\"";
    output += entry.name();
    output += "\",\"size\":\"";
    output += entry.size();
    output += "\"";
    output += "}";
    server.sendContent(output);
    entry.close();
  }
  server.sendContent("]");
  dir.close();
}

void handleNotFound() {
  if (hasSD && loadFromSdCard(server.uri())) {
    return;
  }
  String message = "SDCARD Not Detected\n\n";
  message += "URI: ";
  message += server.uri();
  message += "\nMethod: ";
  message += (server.method() == HTTP_GET) ? "GET" : "POST";
  message += "\nArguments: ";
  message += server.args();
  message += "\n";
  for (uint8_t i = 0; i < server.args(); i++) {
    message += " NAME:" + server.argName(i) + "\n VALUE:" + server.arg(i) + "\n";
  }
  server.send(404, "text/plain", message);
  Serial.print(message);
}

void handleOTAresult() {
  server.sendHeader("Connection", "close");
  server.send(200, "text/plain", (Update.hasError()) ? "FAIL" : "OK");
  Serial.println("OTA update success, rebooting...");
  gfx->begin();
  gfx->fillScreen(GREEN);
  delay(200);
  ESP.restart();
}
  
void handleOTA() {
  HTTPUpload& upload = server.upload();
  if (upload.status == UPLOAD_FILE_START) {
    gfx->begin();
    gfx->fillScreen(RED);
    //Serial.println("Start OTA Update");
    Serial.setDebugOutput(true);
    Serial.printf("Update: %s\n", upload.filename.c_str());
    if (!Update.begin()) { //start with max available size
      Update.printError(Serial);
    }
  } else if (upload.status == UPLOAD_FILE_WRITE) {
    led_status = (led_status == HIGH)? LOW: HIGH;
    digitalWrite(PIN_LED, led_status);
    Serial.print(".");
    if (Update.write(upload.buf, upload.currentSize) != upload.currentSize) {
      Update.printError(Serial);
    }
  } else if (upload.status == UPLOAD_FILE_END) {
    if (Update.end(true)) { //true to set the size to the current progress
      Serial.printf("Update Success: %u\nRebooting...\n", upload.totalSize);
    } else {
      Update.printError(Serial);
    }
    Serial.setDebugOutput(false);
  } else {
    Serial.printf("Update Failed Unexpectedly (likely broken connection): status=%d\n", upload.status);
  }
}

void testWriteFile(fs::FS &fs, const char *path, uint8_t *buf, int len) {
  unsigned long start_time = millis();
  Serial.printf("Test write %s\n", path);

  File file = fs.open(path, FILE_WRITE);
  if (!file) {
    Serial.println("Failed to open file for writing");
    return;
  }
  int loop = 65536 / len;
  while (loop--)
  {
    if (!file.write(buf, len)) {
      Serial.println("Write failed");
      return;
    }
  }
  file.flush();
  file.close();
  unsigned long time_used = millis() - start_time;
  Serial.printf("Write file used: %d ms, %f KB/s\n", time_used, (float)65536 / time_used);
}

void testReadFile(fs::FS &fs, const char *path, uint8_t *buf, int len) {
  unsigned long start_time = millis();
  Serial.printf("Test read %s\n", path);

  File file = fs.open(path);
  if (!file) {
    Serial.println("Failed to open file for reading");
    return;
  }
  int loop = 65536 / len;
  while (loop--)
  {
    if (!file.read(buf, len)) {
      Serial.println("Read failed");
      return;
    }
  }
  file.close();
  unsigned long time_used = millis() - start_time;
  Serial.printf("Read file used: %d ms, %f KB/s\n", time_used, (float)65536 / time_used);
}

void testIO(fs::FS &fs) {
  /* malloc will not reset all bytes to zero, so it is a random data */
  uint8_t *buf = (uint8_t*)malloc(64 * 1024);
  testWriteFile(fs, "/test_1k.bin", buf, 1024);
  testReadFile(fs, "/test_1k.bin", buf, 1024);
  free(buf);
}
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
void loop()
{
  bool exit_loop = false;
  int lcd_bl_en;
  
  if (WiFi.status() == WL_CONNECTED) {
    server.handleClient();
    delay(2);//allow the cpu to switch to other tasks
    
    lcd_bl_en = 1;
    xQueueSendToFront(lcd_bl_queue, &lcd_bl_en, pdMS_TO_TICKS(1));  
    
    // 退出webserver进入深睡条件：按下按键
    if (digitalRead(PIN_KEY) == LOW) {
      delay(20);
      if (digitalRead(PIN_KEY) == LOW) {
        exit_loop = true;
      }
    }
  } else {
    // 如果没有连接就进到loop，说明 a.前面尝试连接wifi炒屎了 或 b.wifi断开了
    // 就直接睡眠了准备正常工作
    exit_loop = true;
  }

  if (exit_loop) {
    Serial.println(F("init done, deep sleep now"));
    gfx->begin();
    lcd_bl_en = 1;
    xQueueSendToFront(lcd_bl_queue, &lcd_bl_en, pdMS_TO_TICKS(1)); 
    gfx->fillScreen(GREEN); 
    delay(500);
    gfx->fillScreen(BLACK);
    lcd_bl_en = 0;
    xQueueSendToFront(lcd_bl_queue, &lcd_bl_en, pdMS_TO_TICKS(1));  
    ledcDetachPin(PIN_TFT_BL);
    delay(5);
    gfx->displayOff();
    esp_sleep_enable_timer_wakeup(uS_TO_S_FACTOR);
    set_io_before_deep_sleep();
    esp_deep_sleep_start();        
  }
  
}

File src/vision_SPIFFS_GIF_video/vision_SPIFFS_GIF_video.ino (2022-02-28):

/*
   Vision V3.2 SPIFFS GIF DEMO
   Github: libc0607/esp32-lcd-vision

   ref: https://github.com/moononournation/RGB565_video

   About this demo:
     - play loop.gif once, and then go into deep sleep;
     - wake by tapping or timer;

   How-to in Arduino IDE:
    Choose:
      ESP32 Dev Module, 240MHz CPU, 80MHz Flash, DIO, 4MB(32Mb),
      No OTA (1M APP/3M SPIFFS), PSRAM Disable;
    check <project_dir>/data/loop.gif; (should less than ~3MB
    check DEEP_SLEEP_TIME_S below;
    upload;
    "ESP32 Sketch Data upload";

   Dependencies:
     Install espressif/arduino-esp32 (V1.0.6) first
      (using V2.0+ together with DFRobot_LIS will cause reset on every i2c.write now)
     moononournation/Arduino_GFX
     bitbank2/JPEGDEC
     DFRobot/DFRobot_LIS (see tapInterrupt example)
     me-no-dev/arduino-esp32fs-plugin (update test file to spiffs)

   This is just an early DEMO to verify all parts of the
   hardware can work properly.
   Many bugs. No guarantee for the performance of this code.

*/

#define GIF_FILENAME "/loop.gif"    // <project_dir>/data/loop.gif 
#define DEEP_SLEEP_TIME_S   30      // wakeup by timer every 30 seconds

#include <DFRobot_LIS.h>
#include <DFRobot_LIS2DW12.h>
#include <WiFi.h>
#include <SPIFFS.h>
#include <Arduino_GFX_Library.h>
#include "gifdec.h"
#include <Wire.h>
#include <esp_sleep.h>
#include <WiFi.h>
#include <rom/rtc.h>
#include <driver/rtc_io.h>
#include <driver/adc.h>
#include <esp_wifi.h>

#define PIN_MISO        2     // sdcard, not used (in this demo)
#define PIN_SCK         14    // sdcard, not used (in this demo)
#define PIN_MOSI        15    // sdcard, not used (in this demo)
#define PIN_SD_CS       13    // sdcard, not used (in this demo)
#define PIN_TFT_CS      5     // LCD
#define PIN_TFT_BL      22    // LCD
#define PIN_TFT_DC      27    // LCD
#define PIN_TFT_RST     33    // LCD
#define PIN_LCD_PWR_EN  19    // LCD, SDcard & temt6000 3v3 power (SY6280AAC on board)
#define PIN_ADC_BAT     35    // battery voltage, with 1M/1M resistor dividor on hardware
#define PIN_TEMP_ADC    36    // not used (in this demo)
#define PIN_BAT_STDBY   37    // cn3165 standby, low == charge finish, ext. pull-up
#define PIN_BAT_CHRG    38    // cn3165 chrg, low == charging, ext. pull-up
#define PIN_ACC_INT1    39    // from accelerometer, push-pull
#define PIN_ACC_INT2    32    // not used
#define PIN_SENSOR_ADC  34    // light sensor (temt6000), to GND if not connected
#define PIN_I2C_SCL     25    // to accelerometer
#define PIN_I2C_SDA     26    // to accelerometer

#define uS_TO_S_FACTOR 1000000ULL
#define BAT_ADC_THRESH_LOW  1700  // analogRead( 1/2*Vbat )

Arduino_DataBus *bus = new Arduino_ESP32SPI(PIN_TFT_DC/* DC */, PIN_TFT_CS /* CS */, PIN_SCK, PIN_MOSI, PIN_MISO, VSPI );
//Arduino_GC9A01  *gfx = new Arduino_GC9A01(bus, PIN_TFT_RST, 2, true);
Arduino_ST7789  *gfx = new Arduino_ST7789(bus, PIN_TFT_RST, 0, true, 240, 240, 0, 0);
RTC_DATA_ATTR int bootCount = 0;

DFRobot_LIS2DW12_I2C acce(&Wire, 0x19);   // sdo/sa0 internal pull-up

void set_io_before_deep_sleep()
{
  pinMode(PIN_TFT_BL, INPUT);
  pinMode(PIN_TFT_CS, INPUT);
  pinMode(PIN_TFT_RST, INPUT);
  pinMode(PIN_MISO, INPUT);
  pinMode(PIN_SCK, INPUT);
  pinMode(PIN_MOSI, INPUT);
  pinMode(PIN_SD_CS, INPUT);
  pinMode(PIN_TFT_DC, INPUT);
  pinMode(1, INPUT);
  pinMode(3, INPUT);
  pinMode(PIN_I2C_SCL, INPUT);
  pinMode(PIN_I2C_SDA, INPUT);
  pinMode(PIN_ACC_INT2, INPUT);
  pinMode(PIN_ADC_BAT, INPUT);
  pinMode(PIN_TEMP_ADC, INPUT);
  pinMode(PIN_SENSOR_ADC, INPUT);

  pinMode(PIN_ACC_INT1, INPUT);
  pinMode(PIN_BAT_STDBY, INPUT);
  pinMode(PIN_BAT_CHRG, INPUT);

  digitalWrite(PIN_LCD_PWR_EN, LOW);
  gpio_hold_en(( gpio_num_t ) PIN_LCD_PWR_EN );
  gpio_deep_sleep_hold_en();
  esp_wifi_stop();

}

void setup()
{
  bootCount++;

  WiFi.mode(WIFI_OFF);
  Serial.begin(115200);
  Serial.print("Vision v3.2, SPIFFS GIF demo; bootcounter: ");
  Serial.println(bootCount);

  gpio_deep_sleep_hold_dis();
  gpio_hold_dis(( gpio_num_t ) PIN_LCD_PWR_EN );
  pinMode(PIN_LCD_PWR_EN, OUTPUT);

  Wire.setPins(PIN_I2C_SDA, PIN_I2C_SCL);
  Serial.print("finding acce. chip");
  while (!acce.begin()) {
    delay(50);
    Serial.print(".");
  }
  Serial.println("!");
  Serial.print("acce. chip id : ");
  Serial.println(acce.getID(), HEX);

  pinMode(PIN_ACC_INT1, INPUT);
  pinMode(PIN_BAT_STDBY, INPUT);
  pinMode(PIN_BAT_CHRG, INPUT);
  esp_sleep_enable_ext0_wakeup((gpio_num_t)PIN_ACC_INT1 , HIGH);
  esp_sleep_enable_timer_wakeup(DEEP_SLEEP_TIME_S * uS_TO_S_FACTOR);

  // find out why we are working
  RESET_REASON rst_reason = rtc_get_reset_reason(0);
  esp_sleep_wakeup_cause_t wakeup_reason = esp_sleep_get_wakeup_cause();

  if (rst_reason == DEEPSLEEP_RESET) {
    // wakeup by acce.
    if (wakeup_reason == ESP_SLEEP_WAKEUP_EXT0) {
      Serial.println("wakeup by ext0");
    } else if (wakeup_reason == ESP_SLEEP_WAKEUP_TIMER) {
      Serial.println("wakeup by timer");
    } else {
      Serial.println("wakeup by yjsnpi");
    }

  } else {
    Serial.println("bootup, init acce");

    acce.setRange(DFRobot_LIS2DW12::e2_g);
    acce.setPowerMode(DFRobot_LIS2DW12::eContLowPwrLowNoise1_12bit);
    acce.setDataRate(DFRobot_LIS2DW12::eRate_100hz);
    acce.enableTapDetectionOnZ(true);
    acce.enableTapDetectionOnY(true);
    acce.setTapThresholdOnY(0.8);
    acce.setTapThresholdOnZ(0.8);
    acce.setTapDur(3);
    acce.setTapMode(DFRobot_LIS2DW12::eBothSingleDouble);
    acce.setInt1Event(DFRobot_LIS2DW12::eDoubleTap);

  }

  uint32_t battery_voltage_adc = analogRead(PIN_ADC_BAT);


  Serial.print("battery_adc: "); Serial.println(battery_voltage_adc);
  if (battery_voltage_adc < BAT_ADC_THRESH_LOW) {
    Serial.println("battery low, deep sleep start");
    set_io_before_deep_sleep();
    esp_deep_sleep_start();
  } else {
    digitalWrite(PIN_LCD_PWR_EN, HIGH);
    delay(50);
  }

  // init lcd
  gfx->begin();
  gfx->fillScreen(BLACK);
  delay(50);  

  // light sensor -> lcd brightness
  float light_sens = analogRead(PIN_SENSOR_ADC);
  float light_sens_norm = light_sens/4096.0;
  light_sens_norm = pow(light_sens_norm, 2.0);
  ledcAttachPin(PIN_TFT_BL, 1); // assign TFT_BL pin to channel 1
  ledcSetup(1, 12000, 8);   // 12 kHz PWM, 8-bit resolution
  uint8_t lcd_brightness = int(light_sens_norm * 224.0) + 31; //  minimum
  ledcWrite(1, lcd_brightness);  // brightness
  Serial.print("lcd_brightness: ");
  Serial.println(lcd_brightness);

  // charger state
  if (digitalRead(PIN_BAT_CHRG) == LOW) {
    Serial.println("battery: charging");
  } else if (digitalRead(PIN_BAT_STDBY) == LOW) {
    Serial.println("battery: full");
  } else {
    Serial.println("battery: not charging");
  }
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

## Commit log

2022-01-31 Add license
    没时间写教程，但是协议还是要先挂上（（
2022-02-01 缓慢更新一点组装教程
2022-02-28 Update README.md
    手抖少个空格草
2022-03-01 Bug fix & enhancements
    这些是在 SDWebServer 例程上的改动
    修了无法右键下载的 bug
    为和我一样的老年人用户调大了字号
    编辑器默认打开 config.txt
    config.txt 使用 ini 的语法高亮
    左侧文件列表中不显示 index.htm, edit.htm 和 ota.htm 防止误操作
    对于后缀 .mjpeg 的文件可以将它加载到 <img> 标签中了（但由于 mjpeg 这个孤儿格式，它依然不能作为视频预览）
    我太菜了
2022-03-15 V3.3 Alpha version of vision_sdcard_mjpeg
    试图增加一些按键操作，但还有 bug ，先传上来
    [vision_sdcard_mjpeg.ino]
2022-03-16 v3.3 alpha bug fix
    [vision_sdcard_mjpeg.ino]
2022-03-16 Mondstadt V2.3
    适配圆版 PCB V3.3，和前面版本的电路及外壳都不兼容
    main: 本体
    cap: 使用 401120 电池时的盖子
    cap-bigbattery: 使用 R40350 圆形电池时的盖子，厚
2022-03-18 Use LED & LCD to indicate the status of uploading
2022-04-01 DO NOT USE IT
    This model does NOT contain the room for circuit
2022-04-01 Liyue stl V2.2
    [liyue-v2.2-cap.STL]
2022-04-01 stl/liyue: update readme
2022-04-14 inazuma stl v1.1(PCB v3.3 GC9A01)
2022-04-16 Update README.md
    别再看错了各位（
2022-04-18 Initial version with BLE iTag (still BUGS)
    The partition table should be updated, OTA upgrade will not work
    [MjpegClass.h, vision_sdcard_mjpeg.ino]
2022-04-18 增加屎山声明
    这屎山如你所愿
2022-04-19 Fix BLE memory leak bug
    [vision_sdcard_mjpeg.ino]
2022-04-19 Try to fix BLE bug
    lld_pdu_get_tx_flush_nb HCI packet count mismatch (0, 1)
    [vision_sdcard_mjpeg.ino]
2022-04-19 BLE bug fix
    but not finished yet
    [vision_sdcard_mjpeg.ino]
2022-04-21 Rewrite LCD backlight controller
    now it has stable 60hz update rate & smoother dimming
2022-04-23 enable double tap to switch video a/b
2022-05-11 Add "always-on" mode
    增加浅睡下的 LCD 常亮模式
    按键保持按下超过一秒（默认）后触发
    这个模式下 CPU 浅睡不解码，屏幕保持最后一帧静态图像，背光最大，总功耗约为正常播放的 1/3
2022-05-15 Use analogReadMilliVolts() in battery monitoring
    测了一堆板子后发现还是得用这个
    顺便可以让网页显示的状态信息好看一点点
2022-07-07 补一个简单教程
2023-03-03 add sumeru vision stl
    不好意思 忘了
